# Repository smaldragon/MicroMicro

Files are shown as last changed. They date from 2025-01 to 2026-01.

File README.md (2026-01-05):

# MicroMicro

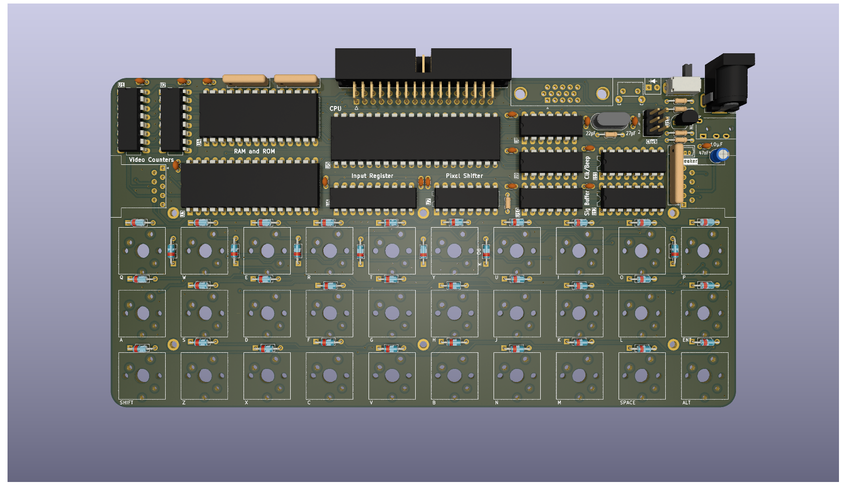
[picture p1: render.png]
PCB Render

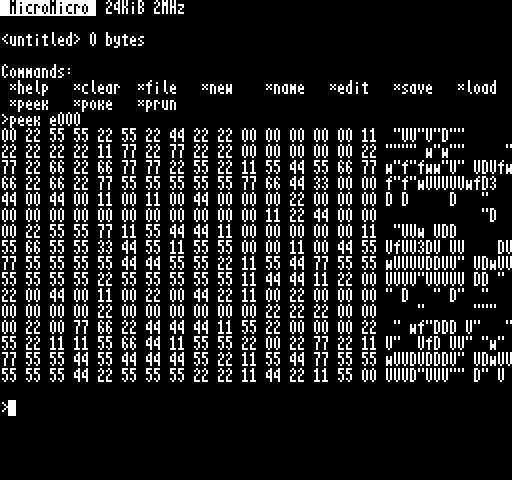
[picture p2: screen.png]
Emulator Screenshot


The MicroMicro (working name) is a project designed for a series I inteded(intend) to write, about how microcomputers work and how to go about developing one. It was designed to use a relatively small amount of integrated circuits (13), not use any programmable chips, microcontrollers or obselete parts, and to be a self-contained architecture that handles its own input and output (ie. not serial based).

With these requirements in mind, the overall specs are humble but capable:
* an 65c02 8bit cpu, running at 2Mhz
* 32KiB of ram, 8K of which are video ram
* 256x240 black and white display, via vga
* 1bit "beeper" audio
* Ultra-compact 30 Key keyboard using the "gherkin" layout
* Tape Interface for loading and storing data
* Cartridge port for rom programs and peripheral expansion
* 2 atari-style joystick ports

*Potential Features*
* custom case made from pcbs

The software side is still up in the air, but I'm aiming for the following features:
* A text editor
* An high-level programming language (undecided on which)
* A built-in assembler
* Saving and loading via the tape interface

This code would likely be custom and documented to follow the article structure of the hardware side of things.

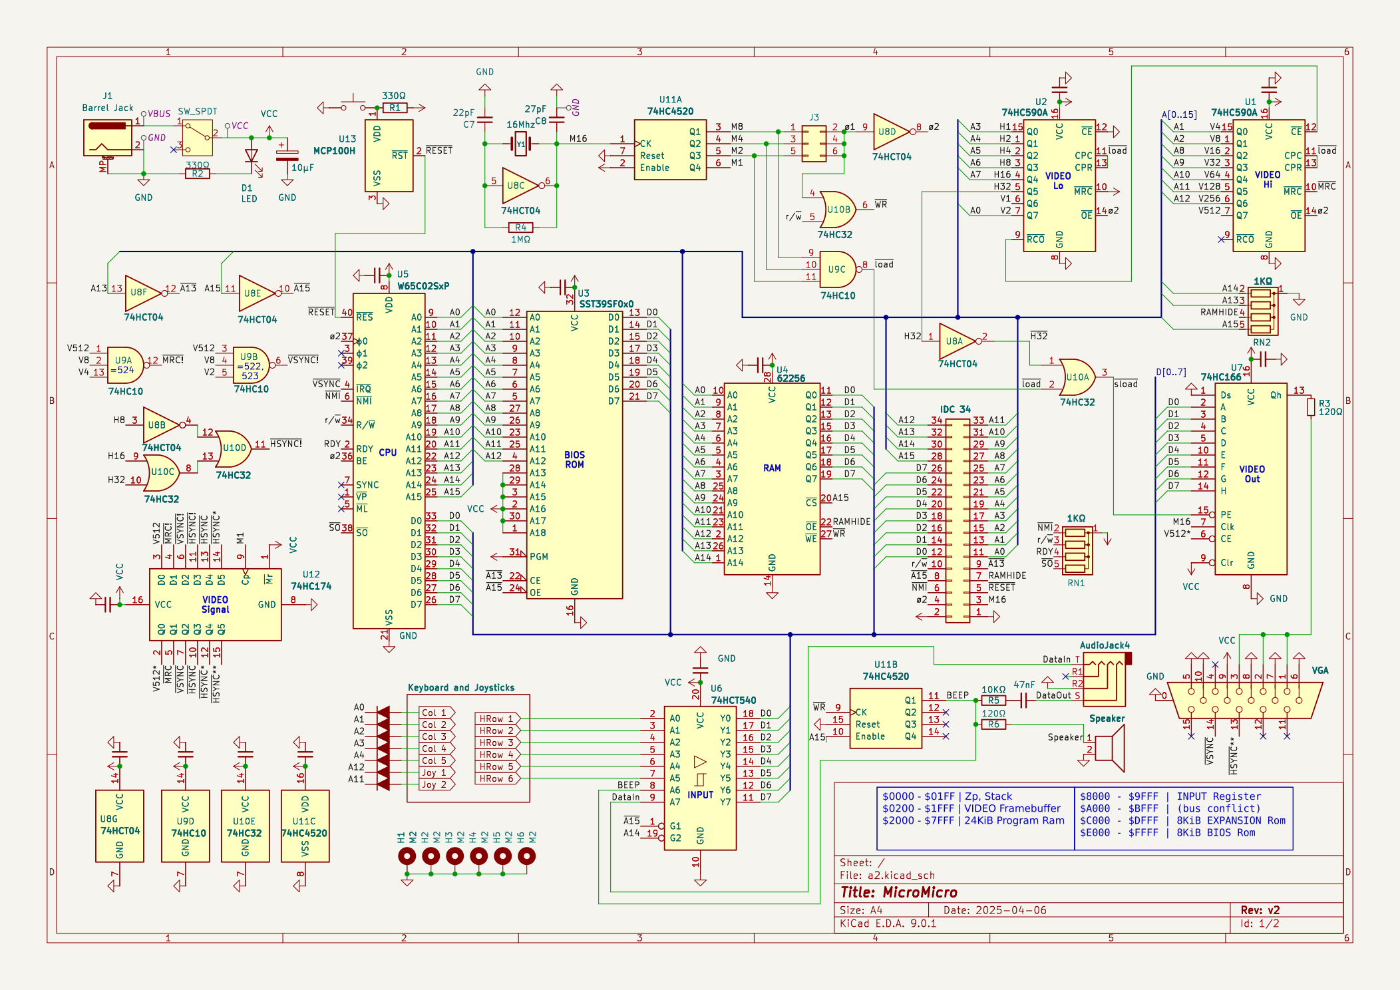
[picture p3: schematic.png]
System Schematic

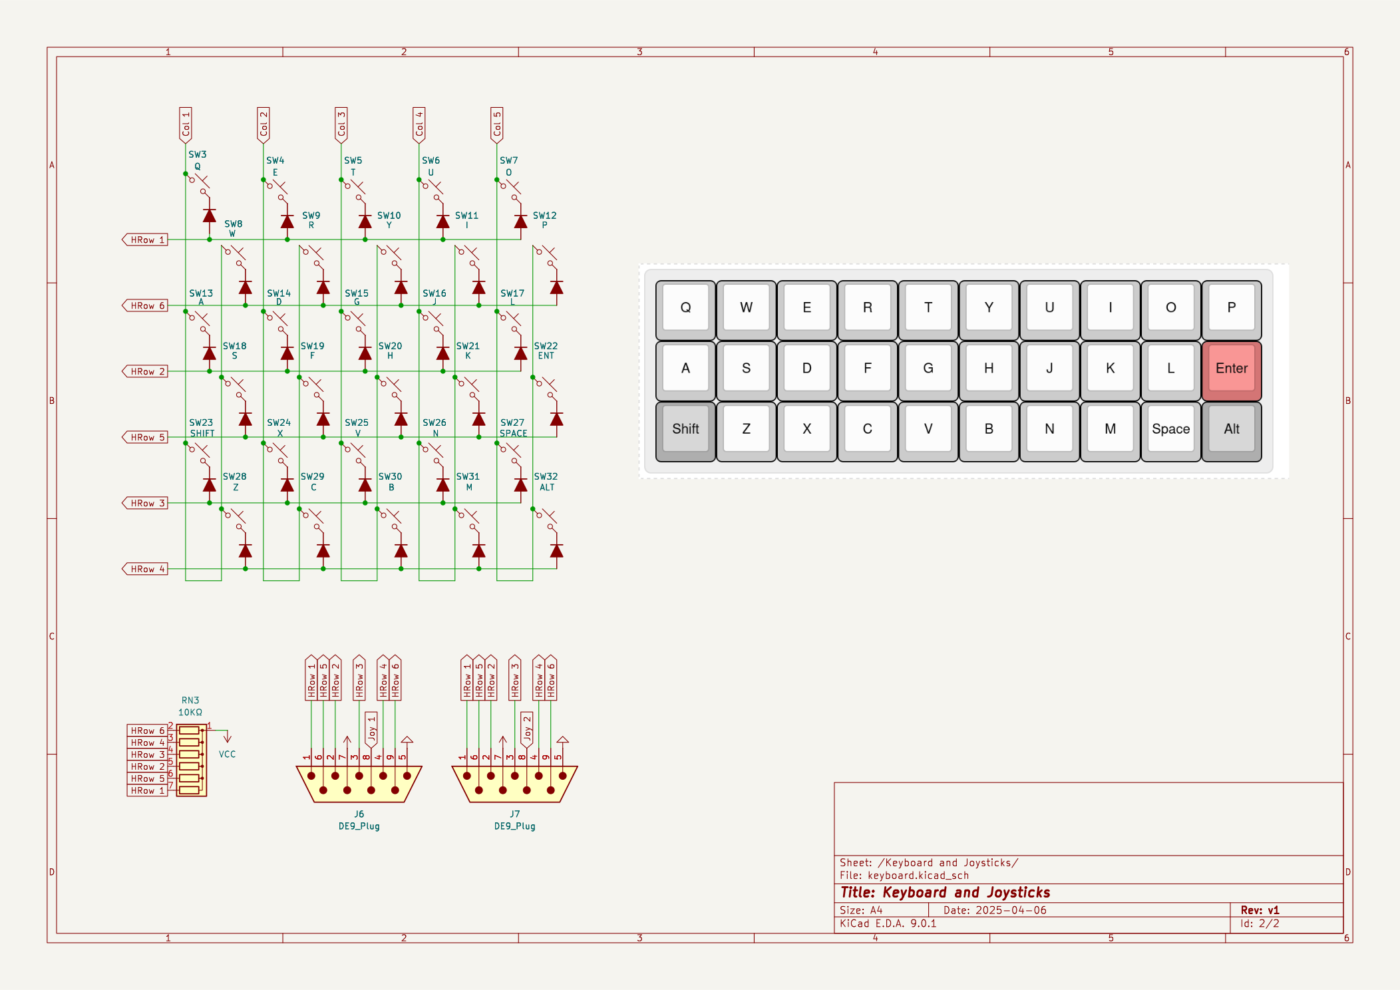
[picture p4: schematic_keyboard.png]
Keyboard Schematic


# Memory Map

```
+---------------------+-------+-----------+
| Name                | Size  | Location  |
+---------------------+-------+-----------+
| Zero Page & Stack   | 512   | 0000-01FF |
| Video Data          | 7680  | 0200-1FFF |
| General Purpose RAM | 24576 | 2000-7FFF |
| IO Registers        | 8192  | 8000-9FFF |
| Expansion ROM       | 8192  | C000-DFFF |
| Bios ROM            | 8192  | E000-FFFF |
+---------------------+-------+-----------+ 
* the area from A000-BFFF is an invalid bus conflict region
```

## Video Data Format

Each byte corresonds to a line of 8 horizontal pixels on the screen. The screen addresses are organized as 32x30 character cells of 8x8 pixels each. 8 Consecutive bytes build one character.

This non-linear format was chosen to speed up the rendering of characters to the screen.

## Keyboard and Joystick

The state of the keyboard and joysticks can be read at the following addresses:

```
+---------------------+----------+-------------------------+
| Name                | Address  | Value (bits 0-5)        |
+---------------------+----------+-------------------------+
| Keyboard Col 1      |   9FFE   |  Q   A  Shf  z   S   W  |
| Keyboard Col 2      |   9FFD   |  E   D   X   C   F   R  |
| Keyboard Col 3      |   9FFB   |  T   G   V   B   H   Y  |
| Keyboard Col 4      |   9FF7   |  U   J   N   M   K   I  |
| Keyboard Col 5      |   9FEF   |  O   L  SPC ALT ENT  P  |
| Joystick 1          |   8FFF   |  ↑   ↓   ←   →   L   R  |
| Joystick 2          |   97FF   |  ↑   ↓   ←   →   L   R  |
+---------------------+----------+-------------------------+
```

## Beeper and Tape Interface

The Beeper is a 1bit register that is used for both audio generation and to load and save programs to tape. It can be accessed through the following registers:

```
+---------------------+-------------+-----------+
| Name                | Address     | Value     |
+---------------------+-------------+-----------+
| State               | 9FFF (read) | TB.. .... |
| Toggle Beeper       | FFFF (write)| 0000 0000 |
+---------------------+-------------+-----------+
T = Tape Input
B = Beeper State (top 2 bits of input register)
```

The tape interface is a 4-pin trs connector that be connected directly to a computer using an appropriate aux cable.

> Note: While these registers can be accessed from alternative locations, the addresses and values on this table ensure no bus conflicts occur.

## Expansion Interface

The MicroMicro has an expansion interface that allows extending the base capabilities of the system in various ways:

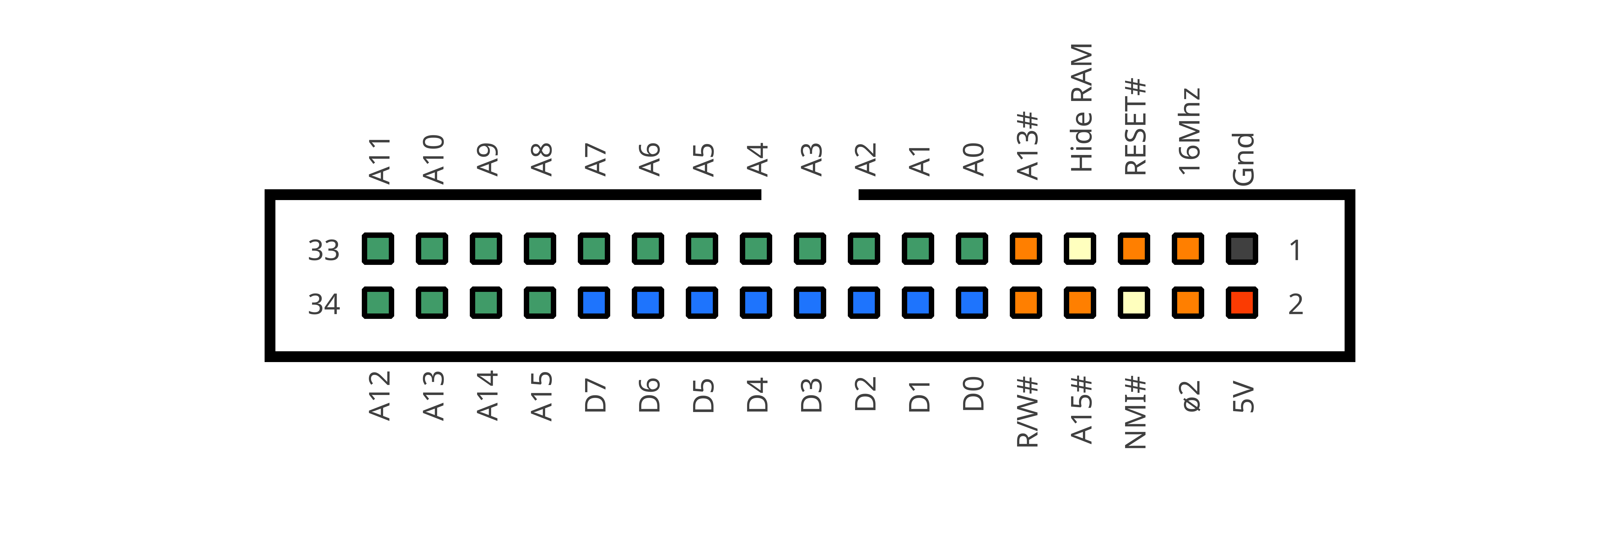
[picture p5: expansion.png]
Expansion Interface


## Generic Banked Expansion Rom

An 8KiB region is set aside in the memory map for expansion roms (`$C000-$DFFF`), the emulator implements a simple banked rom cartridge where the current bank can be switched by reading from `$A0xx`, where `xx` is the bank number, the selected bank is also automatically set to zero on reset.

The bios will automatically jump to address `$C008` on boot if it detects an expansion rom that begins with the sring `CART-RUN`.

Currently expansion roms can be loaded by dragging and dropping a file into the emulator window.

## IC List

The design uses only 12 integrated circuits:

* `65c02` - 8bit CPU
* `62256` - 32KiB SRAM
* `39SF010 or 28C64 or 27C256` - 8KiB Program ROM
* `74hc10` - Tripple 3inNAND
* `74hc14` - Hex inverter
* `74hc32` - Quad 2inOR
* `74hc166` - 8bit parallel-to-serial shift register
* `74hc174` - 6bit d-type latch
* `74hc541` - 8bit buffer
* `74hc590`*2 - 8bit Counters
* `74hc4520`- Dual 4bit Counters

# Operating System

The 8k bios provides a simple command line operating system with the following commands:

| Command | Description |
| --- | --- |
| `help` | Lists all available commands |
| `clear` | Clears the display |
| `file` | The Size and Name of the currently loaded file |
| `new` | Create a new file |
| `name <name>` | Rename the current file |
| `edit` | Open the file editor |
| `save` | Save file to tape |
| `load` | Load file from tape |
| `run` 	 | Run Loaded File |
| `peek <addr> <bytes>` | Read contents of Memory |
| `poke <addr> <bytes>` | Write to Memory |
| `prun <addr>` | Run a Machine Code Subroutine |

More info on the bios can be found [here](Docs/bios.md)

# Changelog

## A2

[Interactive BOM](https://raw.githack.com/smaldragon/MicroMicro/refs/heads/main/Kicad/a2/bom/ibom.html)

* Reset is now performed using a MCP-100 voltage supervisor, this primarly serves to replace the 74HC14 Schmitt Trigger Hex NOT with a 74HCT04, reducing delays, improving reliabiliy of the clock oscillator circuit, and freeing 1 NOT gate for the video circuit
* Video glitches (leftmost pixel column doubled on right, junk at the bottom of the screen) are now gone
* VGA video output is now better centered on the screen
* The small 6mm buzzer has been replaced with an header for a small speaker, improving volume and sound clarity
* Filtering capacitor added to data output
* Needless diodes removed
* Fixed footprint for headphone jack
* 2 additional M2 screw posts added to the center region of the board
* Schematic rearranged

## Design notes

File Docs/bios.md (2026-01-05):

# BIOS Programming Interface

## Interrupt Vectors

The Interrupt Vectors point to the following addresses in Zero Page:

* `$10-$12` - **IRQ** Video Interrupt
* `$13-$15` - **NMI** Expansion Port Interrupt

## Font

The font is located at the start of the BIOS ROM and includes 96 ASCII characters in a 4x8 resolution (768 bytes total):
* `$E000-$E05F` - Row 1
* `$E060-$E1BF` - Row 2
* `$E0C0-$E11F` - Row 3
* `$E120-$E17F` - Row 4
* `$E180-$E1DF` - Row 5
* `$E1E0-$E23F` - Row 6
* `$E240-$E2BF` - Row 7
* `$E2A0-$E2FF` - Row 8

## Control Codes

The MicroMicro uses the following control codes:

## Function API

There is a function jump table located in page $FF00. The current functions are:

* `jsr $FF00` **CIN**  - Returns input character into A (0 if none)
* `jsr $FF03` **COUT**  - Print character in A
* `jsr $FF06` **BEEP** - Pitched sound based on A
* `jsr $FF09` **CMDIN** - Read Command-Line Input, returns start of string into X (zero page address), length of string into Y
* `jsr $FF0C` **GETCURSOR** - Get Current Cursor Position in X (0-63) and Y (0-29)
* `jsr $FF0F` **SETCURSOR** - Set Current Cursor Position using X (0-63) and Y (0-29)

### Control Codes

`CIN`/`COUT` use the following control codes:

* `$03` **ETX** - Escape/Ctrl-C
* `$07` **BEL** - Play a Beep
* `$08` **BS**  - Backspace
* `$0A` **LF**  - Newline
* `$0C` **FF**  - Clear the screen
* `$0D` **CR**  - Return to start of line
* `$10` **CHI** - Turn on Highlighted Text
* `$11` **CNO** - Turn off Highlighted Text
* `$12` **FON** - Turn on the footer
* `$13` **FOF** - Turn off the footer
* `$7F` **DEL** - Erase character at cursor

## Run Carts

An extended rom subroutine will be automatically jumped to (`$C008`) on boot if the rom begins with 'CART-RUN'.

## Command Carts

An extended rom can add new commands to the bios if it beings with 'CART-CMD'. This extra command table beings at `$C008` and uses the same format as the main bios table.

Each table entry is 8 bytes, 6 bytes for the command name, followed by 2 bytes with the subroutine address, the table is terminated with a single zero-byte.

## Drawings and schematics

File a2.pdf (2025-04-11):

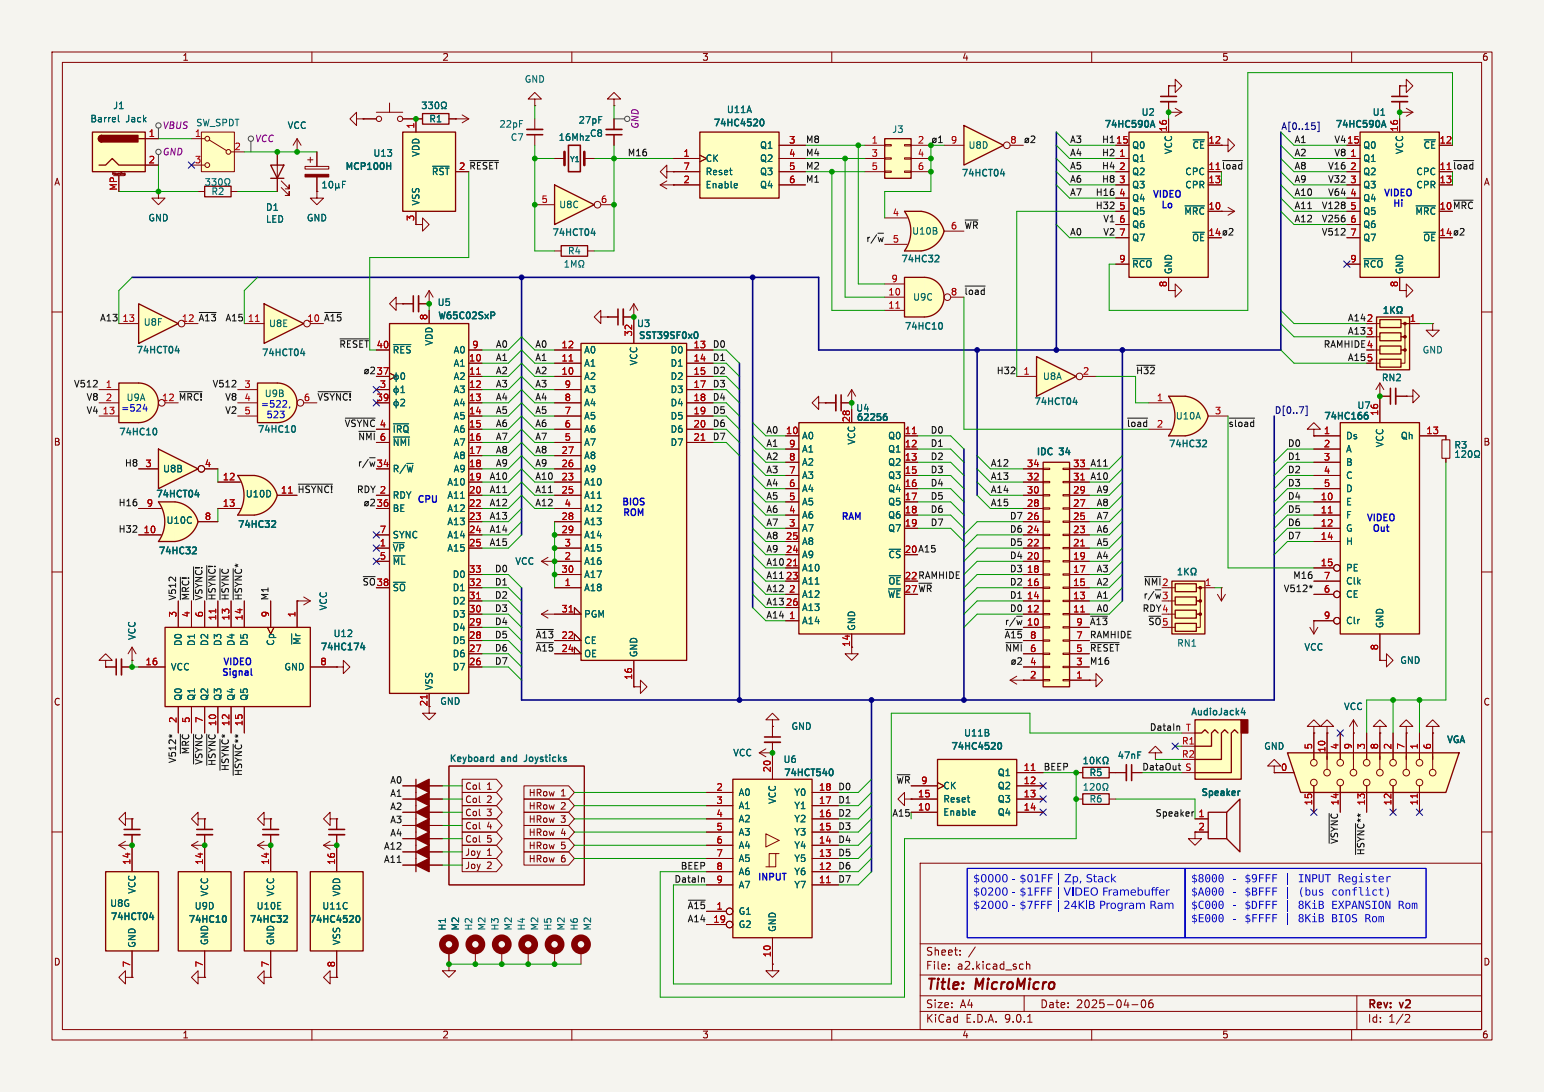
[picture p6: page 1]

8 Q0 15 Q1 1 Q2 2 Q3 3 Q4 4 Q5 5 Q6 6 Q7 7 ~{RCO} 9 U1
~{CE} 12 CPC 11 CPR 13 ~{MRC} 10 ~{OE} 14 VCC 16 GND

7 U3SST39SF0x0 VCC 32 GND 16 A0 12 A1 11 A2 10 A3 9 A4 8 A5 7 A6 6 A7 5 A8 27 A9 26 A10 23 A11 25 A12 4 A13 28 A14 29 A15 3 A16 2 A17 30 A18 1 PGM 31 CE 22 OE 24 D0 13 D1 14 D2 15 D3 17 D4 18 D5 19 D6 20 D7 21 VCC H1 M2

File: a2.kicad_sch Sheet: / Keyboard and Joysticks VCC 14 GND

Joy 1 Col 5 Col 1 Col 3 Col 2

$0000 - $01FF | Zp, Stack
$0200 - $1FFF | VIDEO Framebuffer $2000 - $7FFF | 24KiB Program Ram

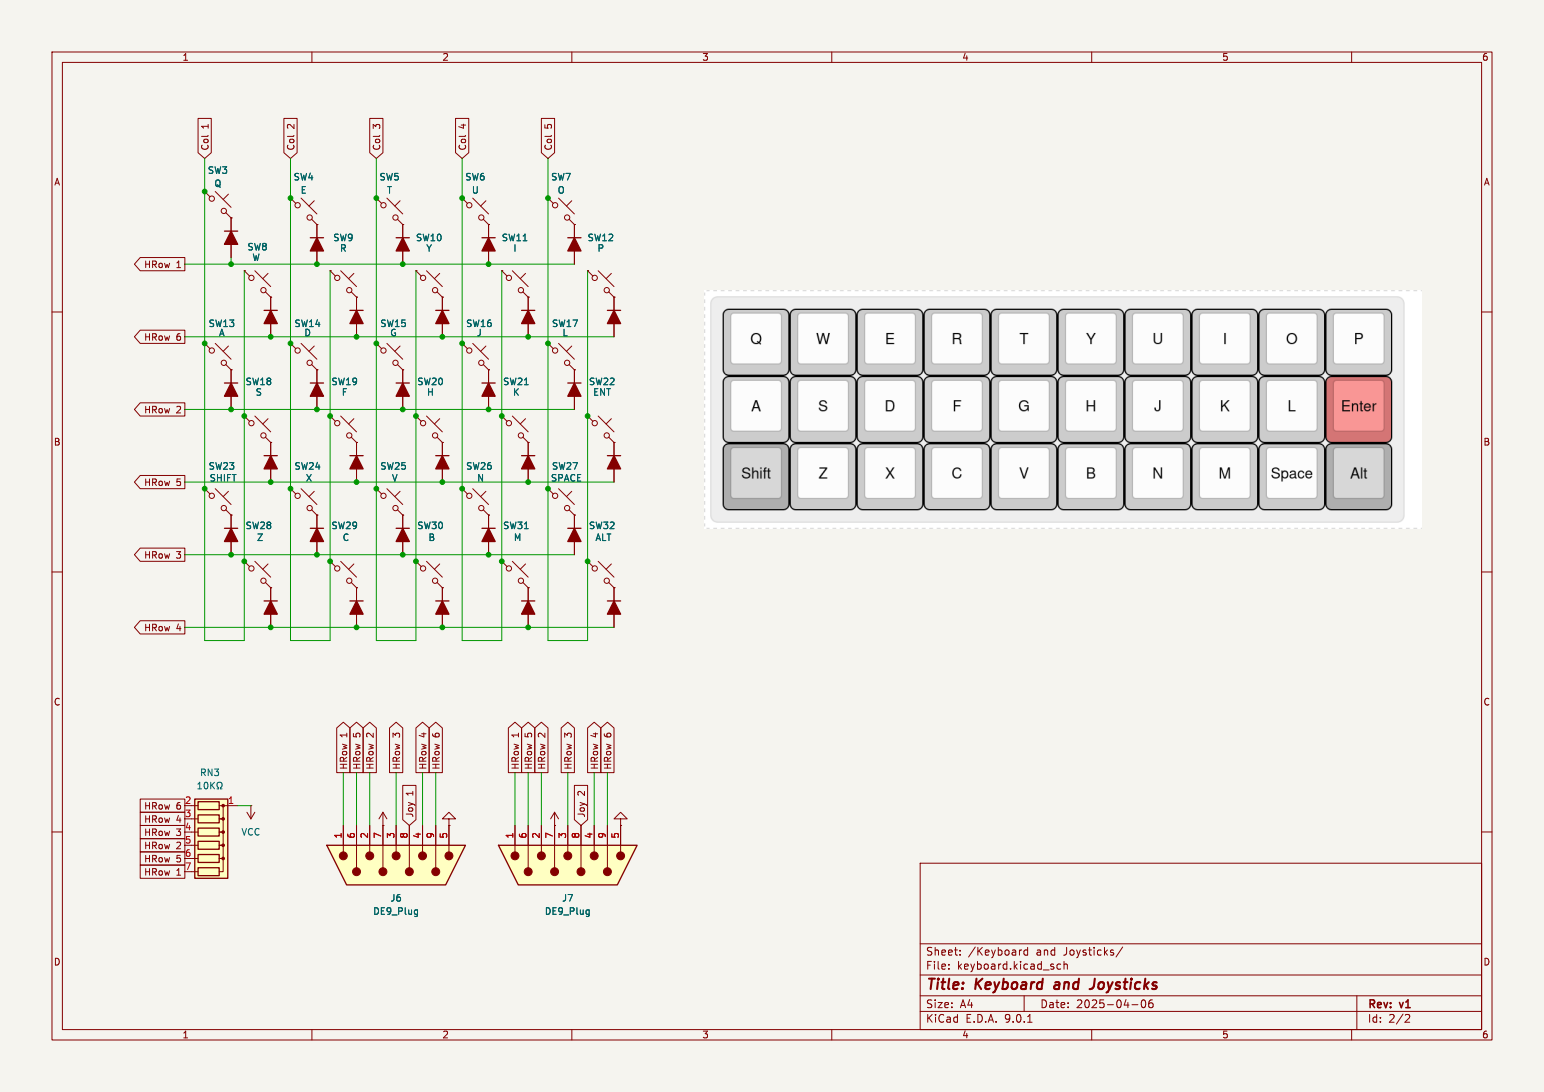
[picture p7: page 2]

Id: 2/2 Title: Keyboard and Joysticks

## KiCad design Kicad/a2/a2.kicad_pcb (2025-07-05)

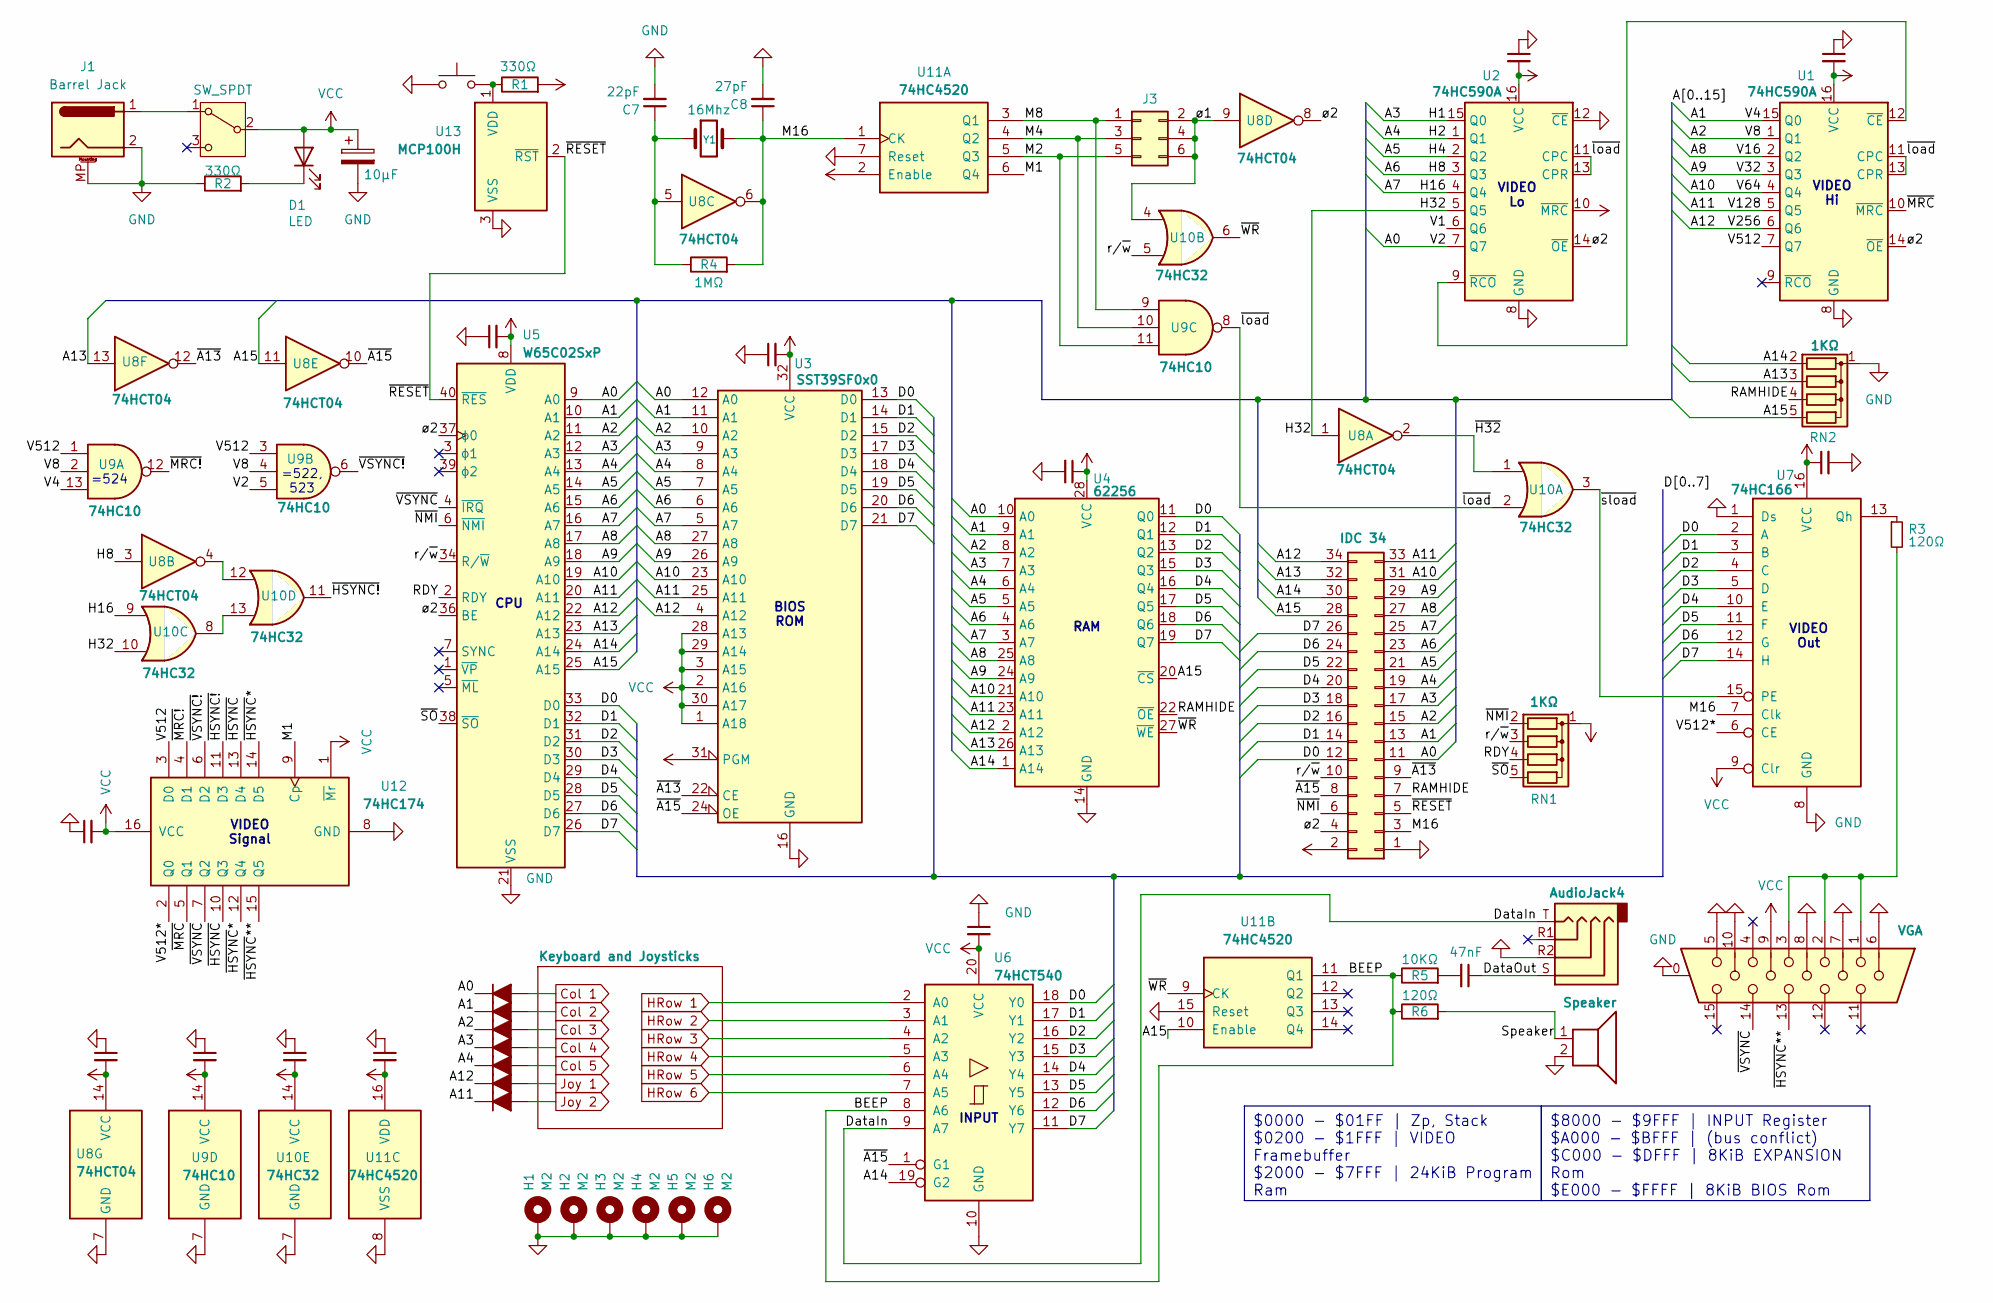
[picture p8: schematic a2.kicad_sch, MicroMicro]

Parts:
C1, C2, C3, C4, C5, C9, C11, C12, C14, C15, C16, C17: 100nF; C_Disc_D3.0mm_W1.6mm_P2.50mm
C6: 10µF; CP_Radial_D4.0mm_P1.50mm
C7: 22pF; C_Disc_D3.0mm_W1.6mm_P2.50mm
C8: 27pF; C_Disc_D3.0mm_W1.6mm_P2.50mm
C10: 47nF; C_Disc_D3.0mm_W1.6mm_P2.50mm
D1: LED; LED_Indicator_D3.0mm_W4.6mm_L6.5mm
D2, D3, D4, D5, D6, D12, D13: 1N4148; D_DO-35_SOD27_P7.62mm_Horizontal
H1, H2, H3, H4, H5, H6: M2; MountingHole_2.2mm_M2_ISO7380_Pad
J1: Barrel Jack; BarrelJack_GCT_DCJ200-10-A_Horizontal
J2: IDC 34; IDC-Header_2x17_P2.54mm_Horizontal
J3: Conn_02x03_Odd_Even; PinHeader_2x03_P2.54mm_Vertical
J4: VGA; DSUB-15-HD_Female_Horizontal_P2.29x1.98mm_EdgePinOffset3.03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
J5: AudioJack4; Jack_3.5mm_PJ320A_Horizontal
LS1: Speaker; Molex_PicoBlade_53047-0210_1x02_P1.25mm_Vertical
R1, R2: 330Ω; R_Axial_DIN0204_L3.6mm_D1.6mm_P7.62mm_Horizontal
R3: 120Ω; R_Axial_DIN0204_L3.6mm_D1.6mm_P5.08mm_Horizontal
R4: 1MΩ; R_Axial_DIN0204_L3.6mm_D1.6mm_P7.62mm_Horizontal
R5: 10KΩ; R_Axial_DIN0204_L3.6mm_D1.6mm_P7.62mm_Horizontal
R6: 120Ω; R_Axial_DIN0204_L3.6mm_D1.6mm_P7.62mm_Horizontal
RN1, RN2: 1KΩ; R_Array_SIP5
SW1: SW_Push; SW_Tactile_SKHH_Angled
SW2: SW_SPDT; SW_Slide_SPDT_Angled_CK_OS102011MA1Q
U1, U2: 74HC590A; DIP-16_W7.62mm_LongPads
U3: SST39SF0x0; DIP-32_W15.24mm_LongPads
U4: 62256; DIP-28_W15.24mm_LongPads
U5: W65C02SxP; DIP-40_W15.24mm
U6: 74HCT540; DIP-20_W7.62mm_LongPads
U7: 74HC166; DIP-16_W7.62mm_LongPads
U8: 74HCT04; DIP-14_W7.62mm_LongPads
U9: 74HC10; DIP-14_W7.62mm_LongPads
U10: 74HC32; DIP-14_W7.62mm_LongPads
U11: 74HC4520; DIP-16_W7.62mm_LongPads
U12: 74HC174; DIP-16_W7.62mm_LongPads
U13: MCP100H; TO-92
Y1: 16Mhz; Crystal_HC49-4H_Vertical

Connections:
/A0: D2.1 (K), J2.11, U2.7 (Q7), U3.12 (A0), U4.10 (A0), U5.9 (A0), U9.5
/A1: D3.1 (K), J2.13, U1.15 (Q0), U3.11 (A1), U4.9 (A1), U5.10 (A1), U9.13
/A2: D4.1 (K), J2.15, U1.1 (Q1), U3.10 (A2), U4.8 (A2), U5.11 (A2), U9.2, U9.4
/A3: D5.1 (K), J2.17, U2.15 (Q0), U3.9 (A3), U4.7 (A3), U5.12 (A3)
/A4: D6.1 (K), J2.19, U2.1 (Q1), U3.8 (A4), U4.6 (A4), U5.13 (A4)
/A5: J2.21, U2.2 (Q2), U3.7 (A5), U4.5 (A5), U5.14 (A5)
/A6: J2.23, U2.3 (Q3), U3.6 (A6), U4.4 (A6), U5.15 (A6), U8.3
/A7: J2.25, U2.4 (Q4), U3.5 (A7), U4.3 (A7), U5.16 (A7), U10.9
/A8: J2.27, U1.2 (Q2), U3.27 (A8), U4.25 (A8), U5.17 (A8)
/A9: J2.29, U1.3 (Q3), U3.26 (A9), U4.24 (A9), U5.18 (A9)
/A10: J2.31, U1.4 (Q4), U3.23 (A10), U4.21 (A10), U5.19 (A10)
/A11: D13.1 (K), J2.33, U1.5 (Q5), U3.25 (A11), U4.23 (A11), U5.20 (A11)
/A12: D12.1 (K), J2.34, U1.6 (Q6), U3.4 (A12), U4.2 (A12), U5.22 (A12)
/A13: J2.32, RN2.3 (R2), U4.26 (A13), U5.23 (A13), U8.13
/A14: J2.30, RN2.2 (R1), U4.1 (A14), U5.24 (A14), U6.19 (G2)
/A15: J2.28, RN2.5 (R4), U4.20 (~CS), U5.25 (A15), U8.11, U11.10 (Enable)
/BEEP: R5.1, R6.1, U6.8 (A6), U11.11 (Q1)
/D0: J2.12, U3.13 (D0), U4.11 (Q0), U5.33 (D0), U6.18 (Y0), U7.2 (A)
/D1: J2.14, U3.14 (D1), U4.12 (Q1), U5.32 (D1), U6.17 (Y1), U7.3 (B)
/D2: J2.16, U3.15 (D2), U4.13 (Q2), U5.31 (D2), U6.16 (Y2), U7.4 (C)
/D3: J2.18, U3.17 (D3), U4.15 (Q3), U5.30 (D3), U6.15 (Y3), U7.5 (D)
/D4: J2.20, U3.18 (D4), U4.16 (Q4), U5.29 (D4), U6.14 (Y4), U7.10 (E)
/D5: J2.22, U3.19 (D5), U4.17 (Q5), U5.28 (D5), U6.13 (Y5), U7.11 (F)
/D6: J2.24, U3.20 (D6), U4.18 (Q6), U5.27 (D6), U6.12 (Y6), U7.12 (G)
/D7: J2.26, U3.21 (D7), U4.19 (Q7), U5.26 (D7), U6.11 (Y7), U7.14 (H)
/DataIn: J5.T, U6.9 (A7)
/DataOut: C10.1, J5.S
/H32: U2.5 (Q5), U8.1, U10.10
/M1: U11.6 (Q4), U12.9 (Cp)
/M2: J3.5, U9.11, U11.5 (Q3)
/M4: J3.3, U9.10, U11.4 (Q2)
/M8: J3.1, U9.9, U11.3 (Q1)
/M16: C8.1, J2.3, R4.2, U7.7 (Clk), U8.6, U11.1 (CK), Y1.2
/RAMHIDE: J2.7, RN2.4 (R3), U4.22 (~OE)
/RDY: RN1.4 (R3), U5.2 (RDY)
/Speaker: LS1.1, R6.2
/V1: U2.6 (Q6)
/V512: U1.7 (Q7), U9.1, U9.3, U12.3 (D0)
/V512*: U7.6 (CE), U12.2 (Q0)
/r/~w: J2.10, RN1.3 (R2), U5.34 (R/~W), U10.5
/~A13: J2.9, U3.22 (CE), U8.12
/~A15: J2.8, U3.24 (OE), U6.1 (G1), U8.10
/~H32: U8.2, U10.1
/~HSYNC!: U10.11, U12.11 (D3)
/~HSYNC: U12.10 (Q3), U12.13 (D4)
/~HSYNC*: U12.12 (Q4), U12.14 (D5)
/~HSYNC**: J4.13, U12.15 (Q5)
/~MRC!: U9.12, U12.4 (D1)
/~MRC: U1.10 (~MRC), U12.5 (Q1)
/~NMI: J2.6, RN1.2 (R1), U5.6 (~NMI)
/~RESET: J2.5, U5.40 (~RES), U13.2 (~RST)
/~SO: RN1.5 (R4), U5.38 (~SO)
/~VSYNC!: U9.6, U12.6 (D2)
/~VSYNC: J4.14, U5.4 (~IRQ), U12.7 (Q2)
/~WR: U4.27 (~WE), U10.6, U11.9 (CK)
/~load: U1.11 (CPC), U1.13 (CPR), U2.11 (CPC), U2.13 (CPR), U9.8, U10.2
/~sload: U7.15 (PE), U10.3
/ø1: J3.2, J3.4, J3.6, U8.9, U10.4
/ø2: J2.4, U1.14 (~OE), U2.14 (~OE), U5.36 (BE), U5.37 (ϕ0), U8.8
Col 1: D2.2 (A); also elsewhere on the board
Col 2: D3.2 (A); also elsewhere on the board
Col 3: D4.2 (A); also elsewhere on the board
Col 4: D5.2 (A); also elsewhere on the board
Col 5: D6.2 (A); also elsewhere on the board
GND: C1.1, C2.1, C3.2, C4.2, C5.1, C6.2, C7.2, C8.2, C9.1, C11.1, C12.1, C14.1, C15.1, C16.1, C17.1, H1.1, H2.1, H3.1, H4.1, H5.1, H6.1, J1.2, J1.MP (MountPin), J2.1, J4.0, J4.5, J4.6, J4.7, J4.8, J4.10, J5.R2, LS1.2, R2.1, RN2.1 (common), SW1.1, U1.8 (GND), U2.8 (GND), U2.12 (~CE), U3.16 (GND), U4.14 (GND), U5.21 (VSS), U6.10 (GND), U7.1 (Ds), U7.8 (GND), U8.7 (GND), U9.7 (GND), U10.7 (GND), U11.7 (Reset), U11.8 (VSS), U11.15 (Reset), U12.8 (GND), U13.3 (VSS); also elsewhere on the board
HRow 1: U6.2 (A0); also elsewhere on the board
HRow 2: U6.3 (A1); also elsewhere on the board
HRow 3: U6.4 (A2); also elsewhere on the board
HRow 4: U6.5 (A3); also elsewhere on the board
HRow 5: U6.6 (A4); also elsewhere on the board
HRow 6: U6.7 (A5); also elsewhere on the board
Joy 1: D12.2 (A); also elsewhere on the board
Joy 2: D13.2 (A); also elsewhere on the board
unnamed: C7.1, R4.1, U8.5, Y1.1
unnamed: C10.2, R5.2
unnamed: D1.1 (K), R2.2
unnamed: J4.1, J4.2, J4.3, R3.2
unnamed: J1.1, SW2.1 (A)
unnamed: U1.12 (~CE), U2.9 (~RCO)
unnamed: R3.1, U7.13 (Qh)
unnamed: U8.4, U10.12
unnamed: U10.8, U10.13
unnamed: R1.1, SW1.2, U13.1 (VDD)
VCC: C1.2, C2.2, C3.1, C4.1, C5.2, C6.1, C9.2, C11.2, C12.2, C14.2, C15.2, C16.2, C17.2, D1.2 (A), J2.2, J4.9, R1.2, RN1.1 (common), SW2.2 (B), U1.16 (VCC), U2.10 (~MRC), U2.16 (VCC), U3.1 (A18), U3.2 (A16), U3.3 (A15), U3.28 (A13), U3.29 (A14), U3.30 (A17), U3.31 (PGM), U3.32 (VCC), U4.28 (VCC), U5.8 (VDD), U6.20 (VCC), U7.9 (Clr), U7.16 (VCC), U8.14 (VCC), U9.14 (VCC), U10.14 (VCC), U11.2 (Enable), U11.16 (VDD), U12.1 (~Mr), U12.16 (VCC); also elsewhere on the board

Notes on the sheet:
VIDEO Lo
=524
BIOS ROM
VIDEO Signal
=522, 523
INPUT
RAM
VIDEO Out
VIDEO Hi
CPU
$8000 - $9FFF | INPUT Register $A000 - $BFFF | (bus conflict) $C000 - $DFFF | 8KiB EXPANSION Rom $E000 - $FFFF | 8KiB BIOS Rom
$0000 - $01FF | Zp, Stack $0200 - $1FFF | VIDEO Framebuffer $2000 - $7FFF | 24KiB Program Ram

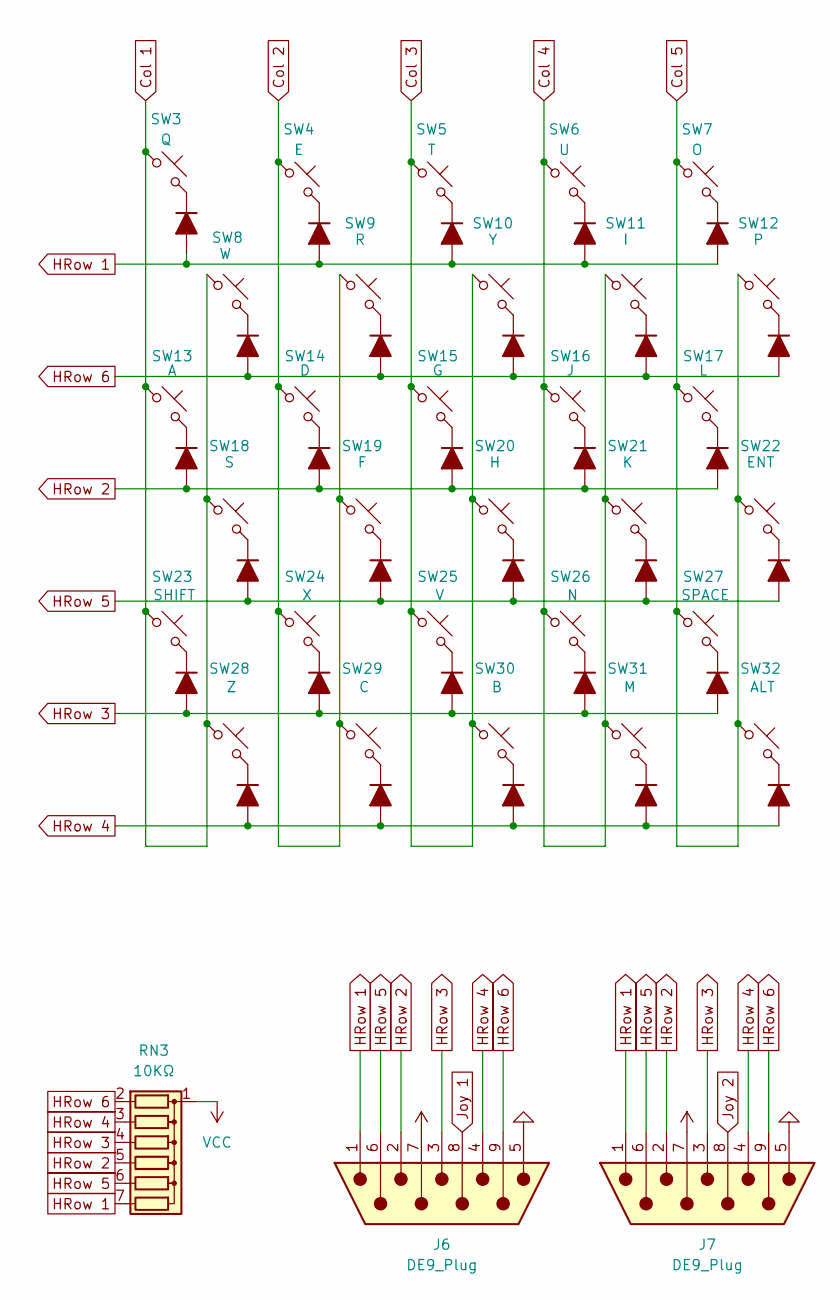
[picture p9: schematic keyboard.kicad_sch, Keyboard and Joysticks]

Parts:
D7, D8, D9, D10, D11, D14, D15, D16, D17, D18, D19, D20, D21, D22, D23, D24, D25, D26, D27, D28, D29, D30, D31, D32, D33, D34, D35, D36, D37, D38: 1N4148; D_DO-35_SOD27_P7.62mm_Horizontal
J6, J7: DE9_Plug; DSUB9-Atari
RN3: 10KΩ; R_Array_SIP7
SW3: Q; SW_Redragon_MX_LowProfile_PCB_1.00u_Other
SW4: E; SW_Redragon_MX_LowProfile_PCB_1.00u_Other
SW5: T; SW_Redragon_MX_LowProfile_PCB_1.00u_Other
SW6: U; SW_Redragon_MX_LowProfile_PCB_1.00u_Other
SW7: O; SW_Redragon_MX_LowProfile_PCB_1.00u_Other
SW8: W; SW_Redragon_MX_LowProfile_PCB_1.00u_Other
SW9: R; SW_Redragon_MX_LowProfile_PCB_1.00u_Other
SW10: Y; SW_Redragon_MX_LowProfile_PCB_1.00u_Other
SW11: I; SW_Redragon_MX_LowProfile_PCB_1.00u_Other
SW12: P; SW_Redragon_MX_LowProfile_PCB_1.00u_Other
SW13: A; SW_Redragon_MX_LowProfile_PCB_1.00u_Other
SW14: D; SW_Redragon_MX_LowProfile_PCB_1.00u_Other
SW15: G; SW_Redragon_MX_LowProfile_PCB_1.00u_Other
SW16: J; SW_Redragon_MX_LowProfile_PCB_1.00u_Other
SW17: L; SW_Redragon_MX_LowProfile_PCB_1.00u_Other
SW18: S; SW_Redragon_MX_LowProfile_PCB_1.00u_Other
SW19: F; SW_Redragon_MX_LowProfile_PCB_1.00u_Other
SW20: H; SW_Redragon_MX_LowProfile_PCB_1.00u_Other
SW21: K; SW_Redragon_MX_LowProfile_PCB_1.00u_Other
SW22: ENT; SW_Redragon_MX_LowProfile_PCB_1.00u_Other
SW23: SHIFT; SW_Redragon_MX_LowProfile_PCB_1.00u_Other
SW24: X; SW_Redragon_MX_LowProfile_PCB_1.00u_Other
SW25: V; SW_Redragon_MX_LowProfile_PCB_1.00u_Other
SW26: N; SW_Redragon_MX_LowProfile_PCB_1.00u_Other
SW27: SPACE; SW_Redragon_MX_LowProfile_PCB_1.00u_Other
SW28: Z; SW_Redragon_MX_LowProfile_PCB_1.00u_Other
SW29: C; SW_Redragon_MX_LowProfile_PCB_1.00u_Other
SW30: B; SW_Redragon_MX_LowProfile_PCB_1.00u_Other
SW31: M; SW_Redragon_MX_LowProfile_PCB_1.00u_Other
SW32: ALT; SW_Redragon_MX_LowProfile_PCB_1.00u_Other

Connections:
Col 1: SW3.1, SW8.1, SW13.1, SW18.1, SW23.1, SW28.1; also elsewhere on the board
Col 2: SW4.1, SW9.1, SW14.1, SW19.1, SW24.1, SW29.1; also elsewhere on the board
Col 3: SW5.1, SW10.1, SW15.1, SW20.1, SW25.1, SW30.1; also elsewhere on the board
Col 4: SW6.1, SW11.1, SW16.1, SW21.1, SW26.1, SW31.1; also elsewhere on the board
Col 5: SW7.1, SW12.1, SW17.1, SW22.1, SW27.1, SW32.1; also elsewhere on the board
GND: J6.5, J7.5; also elsewhere on the board
HRow 1: D7.2 (A), D8.2 (A), D9.2 (A), D10.2 (A), D11.2 (A), J6.1, J7.1, RN3.7 (R6); also elsewhere on the board
HRow 2: D19.2 (A), D20.2 (A), D21.2 (A), D22.2 (A), D23.2 (A), J6.2, J7.2, RN3.5 (R4); also elsewhere on the board
HRow 3: D29.2 (A), D30.2 (A), D31.2 (A), D32.2 (A), D33.2 (A), J6.3, J7.3, RN3.4 (R3); also elsewhere on the board
HRow 4: D34.2 (A), D35.2 (A), D36.2 (A), D37.2 (A), D38.2 (A), J6.4, J7.4, RN3.3 (R2); also elsewhere on the board
HRow 5: D24.2 (A), D25.2 (A), D26.2 (A), D27.2 (A), D28.2 (A), J6.6, J7.6, RN3.6 (R5); also elsewhere on the board
HRow 6: D14.2 (A), D15.2 (A), D16.2 (A), D17.2 (A), D18.2 (A), J6.9, J7.9, RN3.2 (R1); also elsewhere on the board
Joy 1: J6.8; also elsewhere on the board
Joy 2: J7.8; also elsewhere on the board
unnamed: D7.1 (K), SW3.2
unnamed: D8.1 (K), SW4.2
unnamed: D9.1 (K), SW5.2
unnamed: D10.1 (K), SW6.2
unnamed: D11.1 (K), SW7.2
unnamed: D14.1 (K), SW8.2
unnamed: D15.1 (K), SW9.2
unnamed: D16.1 (K), SW10.2
unnamed: D17.1 (K), SW11.2
unnamed: D18.1 (K), SW12.2
unnamed: D19.1 (K), SW13.2
unnamed: D20.1 (K), SW14.2
unnamed: D21.1 (K), SW15.2
unnamed: D22.1 (K), SW16.2
unnamed: D23.1 (K), SW17.2
unnamed: D24.1 (K), SW18.2
unnamed: D25.1 (K), SW19.2
unnamed: D26.1 (K), SW20.2
unnamed: D27.1 (K), SW21.2
unnamed: D28.1 (K), SW22.2
unnamed: D29.1 (K), SW23.2
unnamed: D30.1 (K), SW24.2
unnamed: D31.1 (K), SW25.2
unnamed: D32.1 (K), SW26.2
unnamed: D33.1 (K), SW27.2
unnamed: D34.1 (K), SW28.2
unnamed: D35.1 (K), SW29.2
unnamed: D36.1 (K), SW30.2
unnamed: D37.1 (K), SW31.2
unnamed: D38.1 (K), SW32.2
VCC: J6.7, J7.7, RN3.1 (common); also elsewhere on the board

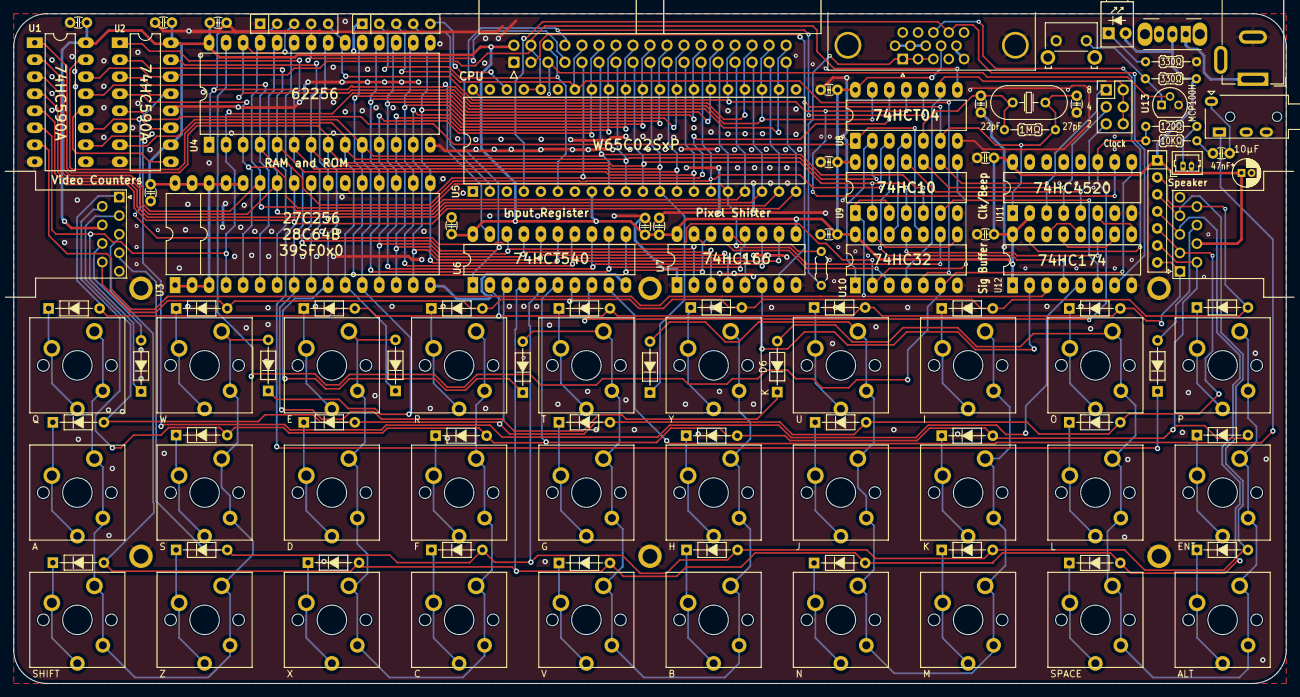
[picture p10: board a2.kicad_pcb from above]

Board: 2 copper layers, 190.0 x 100.0 mm, 123 parts (0 on the bottom side), 113 nets.

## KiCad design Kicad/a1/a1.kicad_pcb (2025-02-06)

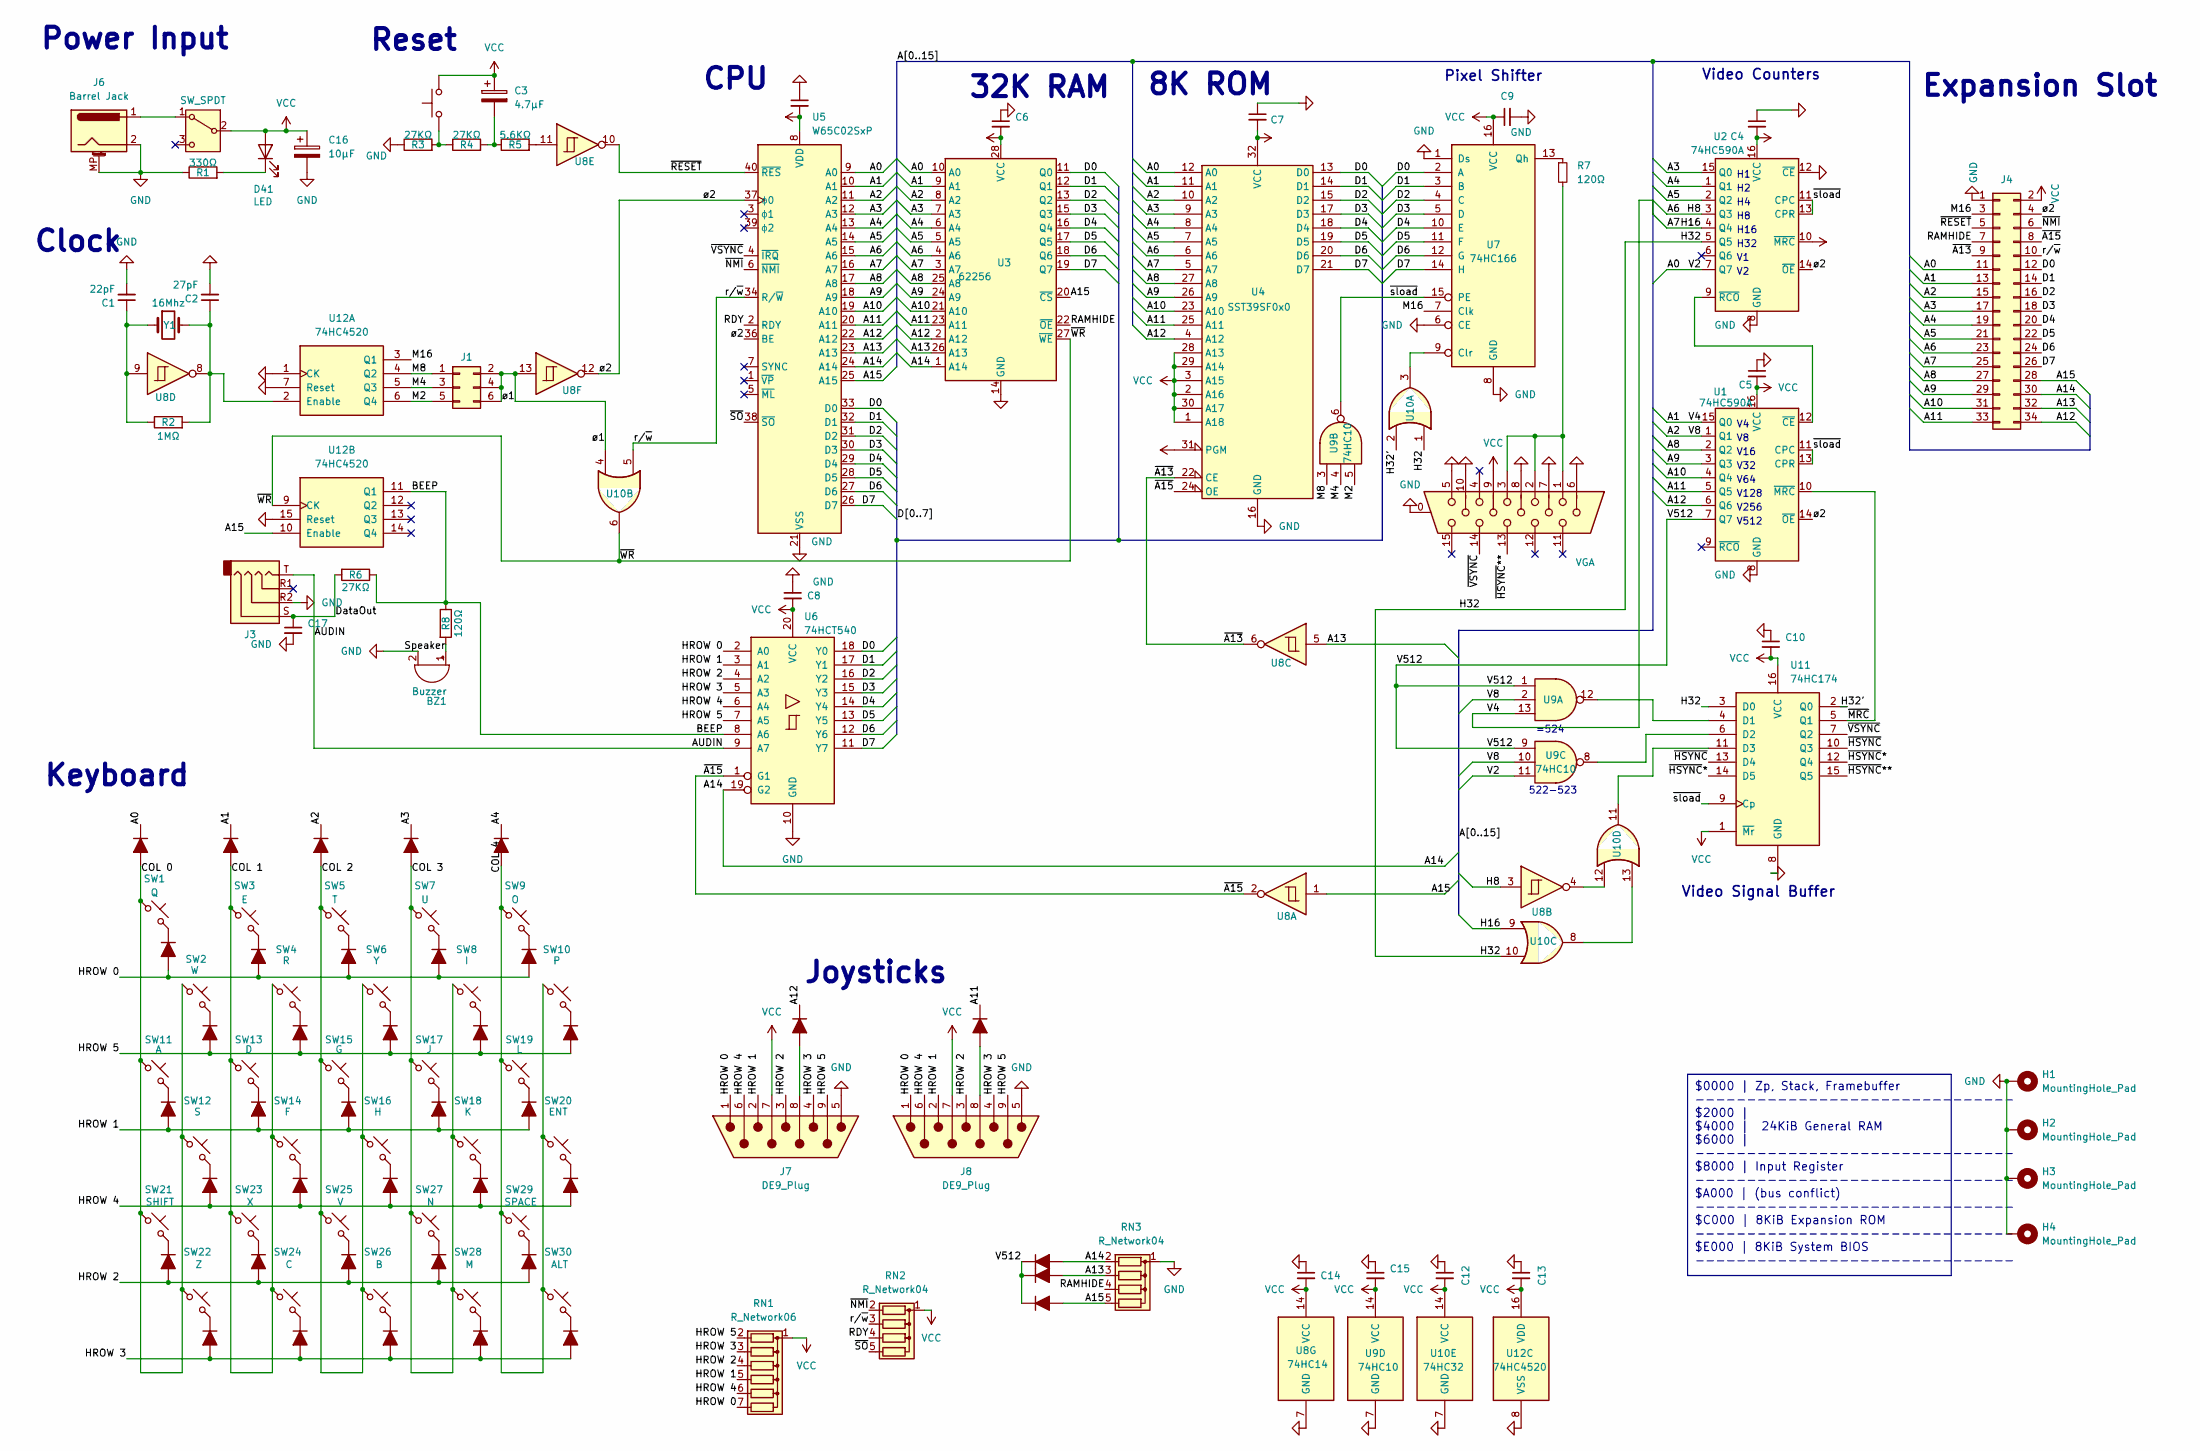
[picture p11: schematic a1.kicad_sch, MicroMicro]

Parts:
BZ1: Buzzer; MagneticBuzzer_Kingstate_KCG0601
C1: 22pF; C_Disc_D3.0mm_W1.6mm_P2.50mm
C2: 27pF; C_Disc_D3.0mm_W1.6mm_P2.50mm
C3: 4.7µF; CP_Radial_D4.0mm_P1.50mm
C4, C5, C6, C7, C8, C9, C10, C11, C12, C13, C14, C15, C17: 100nF; C_Disc_D3.0mm_W1.6mm_P2.50mm
C16: 10µF; CP_Radial_D5.0mm_P2.00mm
D1, D5, D6, D7, D8, D9, D10, D11, D12, D13, D14, D15, D16, D17, D18, D19, D20, D21, D22, D23, D24, D25, D26, D27, D28, D29, D30, D31, D32, D33, D34, D35, D36, D37, D38, D39, D40: 1N4148; D_DO-35_SOD27_P7.62mm_Horizontal
D2, D3, D4: 1N4148; D_DO-34_SOD68_P2.54mm_Vertical_KathodeUp
D41: LED; LED_Indicator_D3.0mm_W4.6mm_L6.5mm
H1, H2, H3, H4: MountingHole_Pad; MountingHole_2.2mm_M2_ISO7380_Pad
J1: Conn_02x03_Odd_Even; PinHeader_2x03_P2.54mm_Vertical
J2: VGA; DSUB-15-HD_Female_Horizontal_P2.29x1.98mm_EdgePinOffset3.03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
J3: AudioJack4; Jack_3.5mm_PJ320A_Horizontal
J4: Conn_02x17_Odd_Even; IDC-Header_2x17_P2.54mm_Horizontal
J6: Barrel Jack; BarrelJack_GCT_DCJ200-10-A_Horizontal
J7, J8: DE9_Plug; DSUB9-Atari
R1: 330Ω; R_Axial_DIN0204_L3.6mm_D1.6mm_P7.62mm_Horizontal
R2: 1MΩ; R_Axial_DIN0204_L3.6mm_D1.6mm_P7.62mm_Horizontal
R3, R4, R6: 27KΩ; R_Axial_DIN0204_L3.6mm_D1.6mm_P7.62mm_Horizontal
R5: 5.6KΩ; R_Axial_DIN0204_L3.6mm_D1.6mm_P7.62mm_Horizontal
R7, R8: 120Ω; R_Axial_DIN0204_L3.6mm_D1.6mm_P7.62mm_Horizontal
RN1: R_Network06; R_Array_SIP7
RN2, RN3: R_Network04; R_Array_SIP5
SW1: Q; SW_Redragon_MX_LowProfile_PCB_1.00u_Other
SW2: W; SW_Redragon_MX_LowProfile_PCB_1.00u_Other
SW3: E; SW_Redragon_MX_LowProfile_PCB_1.00u_Other
SW4: R; SW_Redragon_MX_LowProfile_PCB_1.00u_Other
SW5: T; SW_Redragon_MX_LowProfile_PCB_1.00u_Other
SW6: Y; SW_Redragon_MX_LowProfile_PCB_1.00u_Other
SW7: U; SW_Redragon_MX_LowProfile_PCB_1.00u_Other
SW8: I; SW_Redragon_MX_LowProfile_PCB_1.00u_Other
SW9: O; SW_Redragon_MX_LowProfile_PCB_1.00u_Other
SW10: P; SW_Redragon_MX_LowProfile_PCB_1.00u_Other
SW11: A; SW_Redragon_MX_LowProfile_PCB_1.00u_Other
SW12: S; SW_Redragon_MX_LowProfile_PCB_1.00u_Other
SW13: D; SW_Redragon_MX_LowProfile_PCB_1.00u_Other
SW14: F; SW_Redragon_MX_LowProfile_PCB_1.00u_Other
SW15: G; SW_Redragon_MX_LowProfile_PCB_1.00u_Other
SW16: H; SW_Redragon_MX_LowProfile_PCB_1.00u_Other
SW17: J; SW_Redragon_MX_LowProfile_PCB_1.00u_Other
SW18: K; SW_Redragon_MX_LowProfile_PCB_1.00u_Other
SW19: L; SW_Redragon_MX_LowProfile_PCB_1.00u_Other
SW20: ENT; SW_Redragon_MX_LowProfile_PCB_1.00u_Other
SW21: SHIFT; SW_Redragon_MX_LowProfile_PCB_1.00u_Other
SW22: Z; SW_Redragon_MX_LowProfile_PCB_1.00u_Other
SW23: X; SW_Redragon_MX_LowProfile_PCB_1.00u_Other
SW24: C; SW_Redragon_MX_LowProfile_PCB_1.00u_Other
SW25: V; SW_Redragon_MX_LowProfile_PCB_1.00u_Other
SW26: B; SW_Redragon_MX_LowProfile_PCB_1.00u_Other
SW27: N; SW_Redragon_MX_LowProfile_PCB_1.00u_Other
SW28: M; SW_Redragon_MX_LowProfile_PCB_1.00u_Other
SW29: SPACE; SW_Redragon_MX_LowProfile_PCB_1.00u_Other
SW30: ALT; SW_Redragon_MX_LowProfile_PCB_1.00u_Other
SW31: SW_Push; SW_Tactile_SKHH_Angled
SW32: SW_SPDT; SW_Slide_SPDT_Angled_CK_OS102011MA1Q
U1, U2: 74HC590A; DIP-16_W7.62mm_LongPads
U3: 62256; DIP-28_W15.24mm_LongPads
U4: SST39SF0x0; DIP-32_W15.24mm_LongPads
U5: W65C02SxP; DIP-40_W15.24mm
U6: 74HCT540; DIP-20_W7.62mm_LongPads
U7: 74HC166; DIP-16_W7.62mm_LongPads
U8: 74HC14; DIP-14_W7.62mm_LongPads
U9: 74HC10; DIP-14_W7.62mm_LongPads
U10: 74HC32; DIP-14_W7.62mm_LongPads
U11: 74HC174; DIP-16_W7.62mm_LongPads
U12: 74HC4520; DIP-16_W7.62mm_LongPads
Y1: 16Mhz; Crystal_HC49-4H_Vertical

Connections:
/A0: D1.1 (K), J4.11, U2.7 (Q7), U3.10 (A0), U4.12 (A0), U5.9 (A0), U9.11
/A1: D38.1 (K), J4.13, U1.15 (Q0), U3.9 (A1), U4.11 (A1), U5.10 (A1), U9.13
/A2: D39.1 (K), J4.15, U1.1 (Q1), U3.8 (A2), U4.10 (A2), U5.11 (A2), U9.2, U9.10
/A3: D40.1 (K), J4.17, U2.15 (Q0), U3.7 (A3), U4.9 (A3), U5.12 (A3)
/A4: D37.1 (K), J4.19, U2.1 (Q1), U3.6 (A4), U4.8 (A4), U5.13 (A4)
/A5: J4.21, U2.2 (Q2), U3.5 (A5), U4.7 (A5), U5.14 (A5)
/A6: J4.23, U2.3 (Q3), U3.4 (A6), U4.6 (A6), U5.15 (A6), U8.3
/A7: J4.25, U2.4 (Q4), U3.3 (A7), U4.5 (A7), U5.16 (A7), U10.9
/A8: J4.27, U1.2 (Q2), U3.25 (A8), U4.27 (A8), U5.17 (A8)
/A9: J4.29, U1.3 (Q3), U3.24 (A9), U4.26 (A9), U5.18 (A9)
/A10: J4.31, U1.4 (Q4), U3.21 (A10), U4.23 (A10), U5.19 (A10)
/A11: D5.1 (K), J4.33, U1.5 (Q5), U3.23 (A11), U4.25 (A11), U5.20 (A11)
/A12: D6.1 (K), J4.34, U1.6 (Q6), U3.2 (A12), U4.4 (A12), U5.22 (A12)
/A13: D3.2 (A), J4.32, RN3.3 (R2), U3.26 (A13), U5.23 (A13), U8.5
/A14: D2.2 (A), J4.30, RN3.2 (R1), U3.1 (A14), U5.24 (A14), U6.19 (G2)
/A15: D4.2 (A), J4.28, RN3.5 (R4), U3.20 (~CS), U5.25 (A15), U8.1, U12.10 (Enable)
/AUDIN: J3.T, U6.9 (A7)
/BEEP: R6.1, R8.1, U6.8 (A6), U12.11 (Q1)
/COL 0: D1.2 (A), SW1.1, SW2.1, SW11.1, SW12.1, SW21.1, SW22.1
/COL 1: D38.2 (A), SW3.1, SW4.1, SW13.1, SW14.1, SW23.1, SW24.1
/COL 2: D39.2 (A), SW5.1, SW6.1, SW15.1, SW16.1, SW25.1, SW26.1
/COL 3: D40.2 (A), SW7.1, SW8.1, SW17.1, SW18.1, SW27.1, SW28.1
/COL 4: D37.2 (A), SW9.1, SW10.1, SW19.1, SW20.1, SW29.1, SW30.1
/D0: J4.12, U3.11 (Q0), U4.13 (D0), U5.33 (D0), U6.18 (Y0), U7.2 (A)
/D1: J4.14, U3.12 (Q1), U4.14 (D1), U5.32 (D1), U6.17 (Y1), U7.3 (B)
/D2: J4.16, U3.13 (Q2), U4.15 (D2), U5.31 (D2), U6.16 (Y2), U7.4 (C)
/D3: J4.18, U3.15 (Q3), U4.17 (D3), U5.30 (D3), U6.15 (Y3), U7.5 (D)
/D4: J4.20, U3.16 (Q4), U4.18 (D4), U5.29 (D4), U6.14 (Y4), U7.10 (E)
/D5: J4.22, U3.17 (Q5), U4.19 (D5), U5.28 (D5), U6.13 (Y5), U7.11 (F)
/D6: J4.24, U3.18 (Q6), U4.20 (D6), U5.27 (D6), U6.12 (Y6), U7.12 (G)
/D7: J4.26, U3.19 (Q7), U4.21 (D7), U5.26 (D7), U6.11 (Y7), U7.14 (H)
/DataOut: C17.1, J3.S, R6.2
/H32: U2.5 (Q5), U10.1, U10.10, U11.3 (D0)
/H32': U10.2, U11.2 (Q0)
/HROW 0: D7.2 (A), D8.2 (A), D9.2 (A), D10.2 (A), D11.2 (A), J7.1, J8.1, RN1.7 (R6), U6.2 (A0)
/HROW 1: D17.2 (A), D18.2 (A), D19.2 (A), D20.2 (A), D21.2 (A), J7.2, J8.2, RN1.5 (R4), U6.3 (A1)
/HROW 2: D27.2 (A), D28.2 (A), D29.2 (A), D30.2 (A), D31.2 (A), J7.3, J8.3, RN1.4 (R3), U6.4 (A2)
/HROW 3: D32.2 (A), D33.2 (A), D34.2 (A), D35.2 (A), D36.2 (A), J7.4, J8.4, RN1.3 (R2), U6.5 (A3)
/HROW 4: D22.2 (A), D23.2 (A), D24.2 (A), D25.2 (A), D26.2 (A), J7.6, J8.6, RN1.6 (R5), U6.6 (A4)
/HROW 5: D12.2 (A), D13.2 (A), D14.2 (A), D15.2 (A), D16.2 (A), J7.9, J8.9, RN1.2 (R1), U6.7 (A5)
/M2: J1.5, U9.5, U12.6 (Q4)
/M4: J1.3, U9.4, U12.5 (Q3)
/M8: J1.1, U9.3, U12.4 (Q2)
/M16: J4.3, U7.7 (Clk), U12.3 (Q1)
/RAMHIDE: J4.7, RN3.4 (R3), U3.22 (~OE)
/RDY: RN2.4 (R3), U5.2 (RDY)
/Speaker: BZ1.1 (+), R8.2
/V512: D2.1 (K), D3.1 (K), D4.1 (K), U1.7 (Q7), U9.1, U9.9
/r/~w: J4.10, RN2.3 (R2), U5.34 (R/~W), U10.5
/~A13: J4.9, U4.22 (CE), U8.6
/~A15: J4.8, U4.24 (OE), U6.1 (G1), U8.2
/~HSYNC: U11.10 (Q3), U11.13 (D4)
/~HSYNC*: U11.12 (Q4), U11.14 (D5)
/~HSYNC**: J2.13, U11.15 (Q5)
/~MRC: U1.10 (~MRC), U11.5 (Q1)
/~NMI: J4.6, RN2.2 (R1), U5.6 (~NMI)
/~RESET: J4.5, U5.40 (~RES), U8.10
/~SO: RN2.5 (R4), U5.38 (~SO)
/~VSYNC: J2.14, U5.4 (~IRQ), U11.7 (Q2)
/~WR: U3.27 (~WE), U10.6, U12.9 (CK)
/~sload: U1.11 (CPC), U1.13 (CPR), U2.11 (CPC), U2.13 (CPR), U7.15 (PE), U9.6, U11.9 (Cp)
/ø1: J1.2, J1.4, J1.6, U8.13, U10.4
/ø2: J4.4, U1.14 (~OE), U2.14 (~OE), U5.36 (BE), U5.37 (ϕ0), U8.12
GND: BZ1.2 (-), C1.2, C2.2, C4.1, C5.1, C6.1, C7.1, C8.1, C9.2, C10.1, C11.1, C12.1, C13.1, C14.1, C15.1, C16.2, C17.2, H1.1, H2.1, H3.1, H4.1, J2.0, J2.5, J2.6, J2.7, J2.8, J2.10, J3.R2, J4.1, J6.2, J6.MP (MountPin), J7.5, J8.5, R1.1, R3.1, RN3.1 (common), U1.8 (GND), U2.8 (GND), U2.12 (~CE), U3.14 (GND), U4.16 (GND), U5.21 (VSS), U6.10 (GND), U7.1 (Ds), U7.6 (CE), U7.8 (GND), U8.7 (GND), U9.7 (GND), U10.7 (GND), U11.8 (GND), U12.1 (CK), U12.7 (Reset), U12.8 (VSS), U12.15 (Reset)
unnamed: C1.1, R2.1, U8.9, Y1.1
unnamed: C3.2, R4.2, R5.1
unnamed: D5.2 (A), J8.8
unnamed: D6.2 (A), J7.8
unnamed: D7.1 (K), SW1.2
unnamed: D8.1 (K), SW3.2
unnamed: D9.1 (K), SW5.2
unnamed: D10.1 (K), SW7.2
unnamed: D11.1 (K), SW9.2
unnamed: D12.1 (K), SW10.2
unnamed: D13.1 (K), SW8.2
unnamed: D14.1 (K), SW6.2
unnamed: D15.1 (K), SW4.2
unnamed: D16.1 (K), SW2.2
unnamed: D17.1 (K), SW11.2
unnamed: D18.1 (K), SW13.2
unnamed: D19.1 (K), SW15.2
unnamed: D20.1 (K), SW17.2
unnamed: D21.1 (K), SW19.2
unnamed: D22.1 (K), SW12.2
unnamed: D23.1 (K), SW14.2
unnamed: D24.1 (K), SW16.2
unnamed: D25.1 (K), SW18.2
unnamed: D26.1 (K), SW20.2
unnamed: D27.1 (K), SW21.2
unnamed: D28.1 (K), SW23.2
unnamed: D29.1 (K), SW25.2
unnamed: D30.1 (K), SW27.2
unnamed: D31.1 (K), SW29.2
unnamed: D32.1 (K), SW22.2
unnamed: D33.1 (K), SW24.2
unnamed: D34.1 (K), SW26.2
unnamed: D35.1 (K), SW28.2
unnamed: D36.1 (K), SW30.2
unnamed: D41.1 (K), R1.2
unnamed: J2.1, J2.2, J2.3, R7.2
unnamed: R3.2, R4.1, SW31.1
unnamed: R5.2, U8.11
unnamed: J6.1, SW32.1 (A)
unnamed: U1.12 (~CE), U2.9 (~RCO)
unnamed: U7.9 (Clr), U10.3
unnamed: R7.1, U7.13 (Qh)
unnamed: U8.4, U10.12
unnamed: U10.8, U10.13
unnamed: U9.12, U11.4 (D1)
unnamed: U9.8, U11.6 (D2)
unnamed: U10.11, U11.11 (D3)
unnamed: C2.1, R2.2, U8.8, U12.2 (Enable), Y1.2
VCC: C3.1, C4.2, C5.2, C6.2, C7.2, C8.2, C9.1, C10.2, C11.2, C12.2, C13.2, C14.2, C15.2, C16.1, D41.2 (A), J2.9, J4.2, J7.7, J8.7, RN1.1 (common), RN2.1 (common), SW31.2, SW32.2 (B), U1.16 (VCC), U2.10 (~MRC), U2.16 (VCC), U3.28 (VCC), U4.1 (A18), U4.2 (A16), U4.3 (A15), U4.28 (A13), U4.29 (A14), U4.30 (A17), U4.31 (PGM), U4.32 (VCC), U5.8 (VDD), U6.20 (VCC), U7.16 (VCC), U8.14 (VCC), U9.14 (VCC), U10.14 (VCC), U11.1 (~Mr), U11.16 (VCC), U12.16 (VDD)

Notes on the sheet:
$0000 | Zp, Stack, Framebuffer ------------------------------- $2000 | $4000 | 24KiB General RAM $6000 | ------------------------------- $8000 | Input Register ------------------------------- $A000 | (bus conflict) ------------------------------- $C000 | 8KiB Expansion ROM -------------------------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
Video Signal Buffer
Pixel Shifter
=524
H16
Expansion Slot
32K RAM
522-523
Keyboard
Power Input
CPU
V128
H32
Video Counters
V32
V64
Joysticks
V16
Clock
V512
V256
Reset
8K ROM

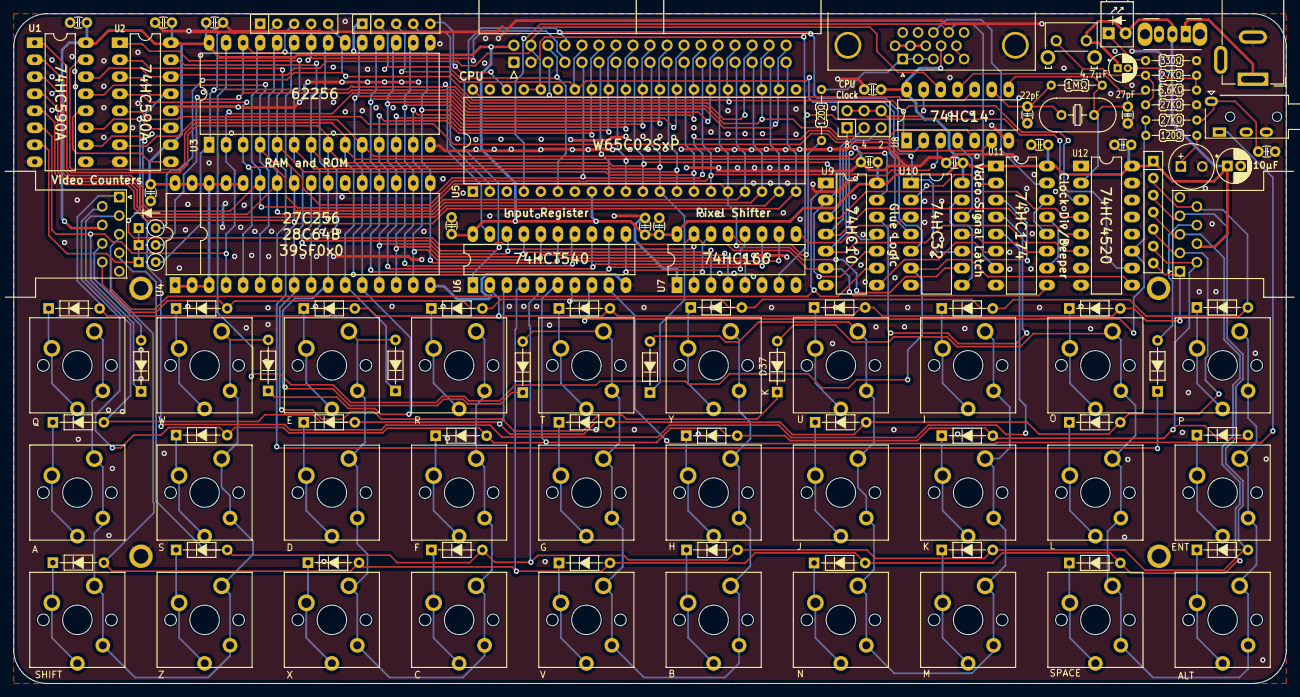
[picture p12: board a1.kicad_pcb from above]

Board: 2 copper layers, 190.0 x 100.0 mm, 126 parts (0 on the bottom side), 113 nets.

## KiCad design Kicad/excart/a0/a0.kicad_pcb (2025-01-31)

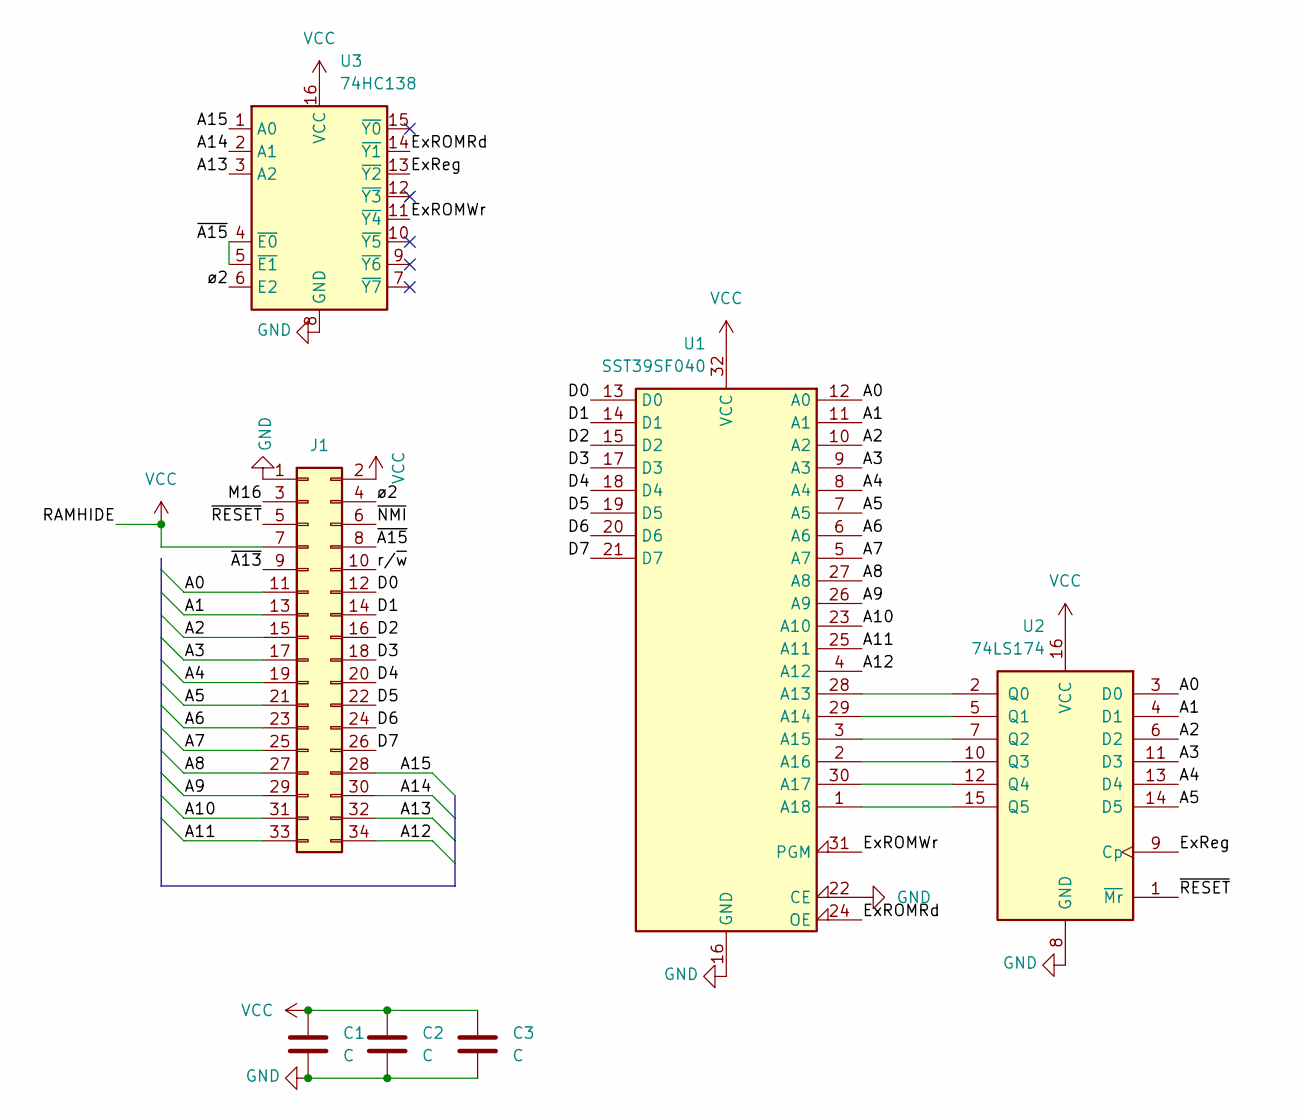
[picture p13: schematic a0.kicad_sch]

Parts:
C1, C2, C3: C; C_Disc_D3.0mm_W1.6mm_P2.50mm
J1: Conn_02x17_Odd_Even; IDC-Header_2x17_P2.54mm_Horizontal
U1: SST39SF040; DIP-32_W15.24mm_LongPads
U2: 74LS174; DIP-16_W7.62mm_LongPads
U3: 74HC138; DIP-16_W7.62mm_LongPads

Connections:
/A0: J1.11, U1.12 (A0), U2.3 (D0)
/A1: J1.13, U1.11 (A1), U2.4 (D1)
/A2: J1.15, U1.10 (A2), U2.6 (D2)
/A3: J1.17, U1.9 (A3), U2.11 (D3)
/A4: J1.19, U1.8 (A4), U2.13 (D4)
/A5: J1.21, U1.7 (A5), U2.14 (D5)
/A6: J1.23, U1.6 (A6)
/A7: J1.25, U1.5 (A7)
/A8: J1.27, U1.27 (A8)
/A9: J1.29, U1.26 (A9)
/A10: J1.31, U1.23 (A10)
/A11: J1.33, U1.25 (A11)
/A12: J1.34, U1.4 (A12)
/A13: J1.32, U3.3 (A2)
/A14: J1.30, U3.2 (A1)
/A15: J1.28, U3.1 (A0)
/D0: J1.12, U1.13 (D0)
/D1: J1.14, U1.14 (D1)
/D2: J1.16, U1.15 (D2)
/D3: J1.18, U1.17 (D3)
/D4: J1.20, U1.18 (D4)
/D5: J1.22, U1.19 (D5)
/D6: J1.24, U1.20 (D6)
/D7: J1.26, U1.21 (D7)
/ExROMRd: U1.24 (OE), U3.14 (~Y1)
/ExROMWr: U1.31 (PGM), U3.11 (~Y4)
/ExReg: U2.9 (Cp), U3.13 (~Y2)
/M16: J1.3
/r/~w: J1.10
/~A13: J1.9
/~A15: J1.8, U3.4 (~E0), U3.5 (~E1)
/~NMI: J1.6
/~RESET: J1.5, U2.1 (~Mr)
/ø2: J1.4, U3.6 (E2)
GND: C1.1, C2.1, C3.1, J1.1, U1.16 (GND), U1.22 (CE), U2.8 (GND), U3.8 (GND)
unnamed: U1.28 (A13), U2.2 (Q0)
unnamed: U1.29 (A14), U2.5 (Q1)
unnamed: U1.3 (A15), U2.7 (Q2)
unnamed: U1.2 (A16), U2.10 (Q3)
unnamed: U1.30 (A17), U2.12 (Q4)
unnamed: U1.1 (A18), U2.15 (Q5)
VCC: C1.2, C2.2, C3.2, J1.2, J1.7, U1.32 (VCC), U2.16 (VCC), U3.16 (VCC)

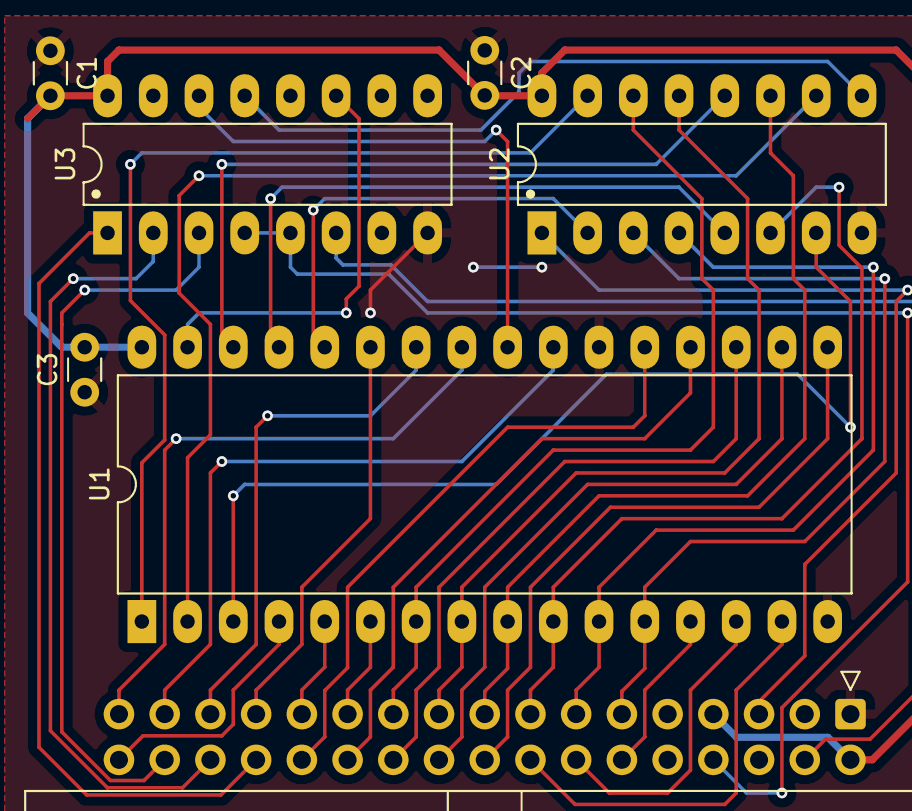
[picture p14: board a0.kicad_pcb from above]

Board: 2 copper layers, 7 parts (0 on the bottom side), 38 nets.

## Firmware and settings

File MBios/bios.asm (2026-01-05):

# -------------------------
.cpu 65c02
# Global Temp Registers
.zp r0
.zp r1
.zp r2
.zp r3
.zp r4
.zp r5
.zp r6
.zp r7
.zp r8
.zp r9
.zp rA
.zp rB
.zp rC
.zp EXTRATBL 2
.zp CPUFreq
.zp IRQ 3
.zp NMI 3

#.zp FSIZE 2 using BotPTR for now instead


.val MAXSIZE $6000

.org [$E000]
  .asm stdio
  .asm edit
  .asm lang
  
.zp FNAME 9
.zp RUNCODE 4
.val InputSize 63
.zp Input InputSize+1
.zp InputL
_RESET
  sei; cld
  lda $40; sta <NMI>        # RTI
  
  # -- Clock Speed Calc, stores (clock cyles in a irq)/16 in <rF>
  ## 8 = 2Mhz
  ## 16 = 4Mhz
  ## 32 = 8Mhz
  # align with next irq
  wai
  # interrupt subroutine takes exactly 16 cycles
  lda $65; sta <IRQ+0>      # ADC zp
  lda 0;   sta <IRQ+1>      
  lda $40; sta <IRQ+2>      # RTI
  lda 1;   sta <r0>
  
  # wait loop until the end of the current irq
  ldx 0
  __wait
  inc X; bne (wait)
  
  # activate the irq subroutine
  lda 0
  clc
  cli
  wai
  sta <CPUFreq>
  
  jsr [STDIOINIT]
  
  lda <RUNCODE+0>;cmp 'R'; bne (cold)
  lda <RUNCODE+1>;cmp 'u'; bne (cold)
  lda <RUNCODE+2>;cmp 'n'; bne (cold)
  lda <RUNCODE+3>;cmp '!'; bne (cold)
    bra (warm)
  __cold
  jsr [Edit_New]
  stz <FNAME>
  __warm
  lda 'R'; sta <RUNCODE+0>
  lda 'u'; sta <RUNCODE+1>
  lda 'n'; sta <RUNCODE+2>
  lda '!'; sta <RUNCODE+3>
  
_INIT
  lda 32; jsr [BEEP]
  lda 24; jsr [BEEP]
  
  lda string1.lo; sta <r4>
  lda string1.hi; sta <r5>
  jsr [SOUT]
  clc; lda <CPUFreq>; lsr A; lsr A; adc $30; jsr [COUT]
  lda string2.lo; sta <r4>
  lda string2.hi; sta <r5>
  jsr [SOUT]
  
  
  # By default EXTRATBL points to a zero byte within itself
  lda EXTRATBL.lo+1; sta <EXTRATBL>
  lda 0; sta <EXTRATBL+1>
  
  #lda TestCmdTable.lo; sta <EXTRATBL+0>
  #lda TestCmdTable.hi; sta <EXTRATBL+1>
  
  __CartRunCheck
  # Check for CART-RUN
  lda [$C000]; cmp 'C'; bne (done)
  lda [$C001]; cmp 'A'; bne (done)
  lda [$C002]; cmp 'R'; bne (done)
  lda [$C003]; cmp 'T'; bne (done)
  lda [$C004]; cmp '-'; bne (done)
  lda [$C005]; cmp 'R'; bne (done)
  lda [$C006]; cmp 'U'; bne (done)
  lda [$C007]; cmp 'N'; bne (done)
    jsr [$C008]
  ___done
  __CartCmdCheck
  # Check for CART-CMD
  lda [$C000]; cmp 'C'; bne (done)
  lda [$C001]; cmp 'A'; bne (done)
  lda [$C002]; cmp 'R'; bne (done)
  lda [$C003]; cmp 'T'; bne (done)
  lda [$C004]; cmp '-'; bne (done)
  lda [$C005]; cmp 'C'; bne (done)
  lda [$C006]; cmp 'M'; bne (done)
  lda [$C007]; cmp 'D'; bne (done)
    lda $08; sta <EXTRATBL+0>
    lda $C0; sta <EXTRATBL+1>
  ___done
    
_MAIN
  jsr [cFILE]
  jsr [cHELP]
  stz <InputL>
  lda '>'; jsr [COUT]
    
__fim
  lda 0
  jsr [CIN]; beq (fim)
  
  cmp LF; beq (lf)
  cmp BS; beq (bs)
  
  pha
  lda <InputL>; cmp InputSize; beq (inputfull)
  pla;pha
  jsr [COUT]
  pla
  ldx <InputL>; sta <Input+X>; inc <InputL>
bra (fim)
___lf
  jsr [COUT]
  lda  CR; jsr [COUT]
  ldx <InputL>; lda $00; sta <Input+X>
  jsr [CmdRun]
  stz <InputL>
  lda '>'; jsr [COUT]
bra (fim)
___bs
  pha
  lda <InputL>; beq (inputfull)
  dec <InputL>
  pla
  jsr [COUT]
bra (fim)
___inputfull
  lda BEL; jsr [COUT]
bra (fim)

_hInputH8
	# -- Parse an 8bit value hex value from input
	# in:
	#	X→Input Index
	# out:
	#	X→Incremented Input Index
	#	C→Successful
	#	A→Parsed Value
	
	dec X
	__skipspaces
		inc X
		cpx InputSize-1; bcs (fail)
		lda <Input+X>; beq (fail)

	cmp ' '; beq (skipspaces)
	
	# Read Input
	lda <Input+X>; sta <0>
	inc X
	lda <Input+X>; sta <1>
	inc X
	
	phx; lda <0>; ldx <1>
	jsr [AsciiToHex]
	plx; bcc (fail)
	
	__succ
	sec; rts
	__fail
	clc; rts

_CMDIN
  ldx Input.lo
  ldy <InputL>
rts

_cUNKNOWN
  SPrint string_unknown
rts

_cHELP
  SPrint string_help
  sei
  ldx 0
  __loop
    lda [CmdTable+X]; beq (done)
    phx
    SPrint string_list
    plx
    ldy 6
    ___print
      phy; phx; lda [CmdTable+X]
      jsr [COUT]; plx; ply
    sei; inc X; dec Y; bne (print)
    inc X; inc X
  bne (loop)
  ___done
  ldy 0
  __extraloop
    lda [<EXTRATBL>+Y]; beq (done)
    phy
    SPrint string_list
    ply
    ldx 6
    ___print
      phy;phx; lda [<EXTRATBL>+Y]
      
      # Reject Invalid Characters
      beq (bad)
      cmp $7F; bcs (bad)
      cmp $20; bcc (bad)
      jsr [COUT]; plx; ply
    sei; inc Y; dec X; bne (print)
    inc Y; inc Y
  bne (extraloop)
  __done
  cli
  lda CR; jsr [COUT]
  lda LF; jsr [COUT]
rts
__bad
  plx; ply
  cli
  ldx 0
  
  ___send
  lda [error+X]; beq (done); phx; jsr [COUT]; plx; inc X; cpx 64; bne (send)
  ___done
  
  lda EXTRATBL.lo+1; sta <EXTRATBL>
  lda 0; sta <EXTRATBL+1>
rts
___error
.byte CR,LF, CHI,' ERROR ',CNO,' bad cartridge',CR,LF,$00
#jmp [MAIN]


_cFILE
  lda <FNAME>; beq (unnamedfile)
  lda CHI; jsr [COUT]
  lda FNAME.lo; sta <r4>; stz <r5>
  jsr [SOUT]
  lda CNO; jsr [COUT]
  bra (continue)
  __unnamedfile
  lda txtun.lo; sta <r4>; lda txtun.hi; sta <r5>
  jsr [SOUT]
  __continue
  lda ' '; jsr [COUT]
  sec
  lda <BotPTR+0>; sbc $2000.lo; sta <r0>
  lda <BotPTR+1>; sbc $2000.hi; sta <r1>
  jsr [BinToDecPrint]
  lda txt2.lo; sta <r4>
  lda txt2.hi; sta <r5>
  jsr [SOUT]
rts
__txt2
.byte ' bytes',CR,LF,CR,LF,$00
__txtun
.byte "<untitled>"

_cCLEAR
  lda FF; jsr [COUT]
rts

_cNEW
  jsr [Edit_New]
  lda $2000.lo; sta <BotPTR+0>
  lda $2000.hi; sta <BotPTR+1>
  stz <FNAME>
  jmp [cFILE]

_cNAME
  ldx 5
  ldy 0
  
  __findstart
    lda <Input+X>; beq (done)
    cmp ' '; bne (cmdStart)
  inc X; cpx <InputL>; beq (done); bra (findstart)
  __cmdStart
    lda <Input+X>; sta [FNAME+Y]
    inc Y; inc X
  cpx <InputL>; beq (done); cpy 8; beq (done); bra (cmdStart)
  __done
  lda 0; sta [FNAME+Y]
  jmp [cFILE]

_cEDIT
	jsr [Edit]
rts

_cSEND
  lda $2000.lo; sta <r0>
  lda $2000.hi; sta <r1>
  lda <BotPTR+0>; sta <r2>
  lda <BotPTR+1>; sta <r3>
  jmp [FileOUT]
  
_cLOAD
jmp [FileIN]


# ------------------------------
# Memory Monitor Functions
_cPRUN
    # -- Run a "program" at specified address
	ldx 4
	jsr [hInputH8]; bcc (break)
		sta <r2>
	jsr [hInputH8]; bcc (break)
		sta <r1>
	lda $4C # (opcode for JMP)
	    sta <r0>
	jsr [r0]
__break
rts
_cPOKE
	ldx 4
	jsr [hInputH8]; bcc (break)
		sta <r7>
	jsr [hInputH8]; bcc (break)
		sta <r6>
		
    ldy 0
	__WriteLoop
		jsr [hInputH8]; bcc (break)
		sta [<r6>+Y]
    inc Y; bra (WriteLoop)
__break
rts
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

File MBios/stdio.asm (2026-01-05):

# -------------------------
# STDIO
#  handles basic terminal input and output functions
# -------------------------
_FONT
.bin "font"

.val FONT_0 FONT+0-32
.val FONT_1 FONT+96-32
.val FONT_2 FONT+192-32
.val FONT_3 FONT+288-32
.val FONT_4 FONT+384-32
.val FONT_5 FONT+480-32
.val FONT_6 FONT+576-32
.val FONT_7 FONT+672-32

#.asm otla

.zp Cursor  2
	.val CursorX Cursor+0
	.val CursorY Cursor+1
.zp CursorFlip 1
.zp CursorTime 1
.zp CursorColour 1
.zp ActiveFooter 1

.val KInpSize 4
.zp KInp    KInpSize

.zp KInpPtr 1
.zp KLast   5
.zp KCur    5
.zp KMod    1
.zp KTime   1
.zp KRepeat 1

# Control Codes
.val ETX $03  # Escape
.val BEL $07  # bell
.val BS  $08  # backspace
.val LF  $0A  # line feed
.val FF  $0C  # form feed
.val CR  $0D  # carriage return
.val CHI $10  # color highlight
.val CNO $11  # color normal
.val FON $12  # Footer ON
.val FOF $13  # Footer OFF
.val DEL $7F  # Delete


.val ALF   $01
.val ARI   $02
.val AUP   $03
.val ADW   $04

.val SPC ' '
.val ENT LF
.val SHF 0
.val ALT 0
.val HSH $23
.val QOT $27


_KMapR1
.byte 'q','a', 0 ,'z','s','w',0,0 # normal
.byte 'Q','A', 0 ,'Z','S','W',0,0 # shift
.byte '1','@', 0 ,'*',HSH,'2',0,0 # alt
.byte ETX,ALF,0 ,'~',ADW,AUP,0,0 # shift+alt

_KMapR2
.byte 'e','d','x','c','f','r',0,0 # normal
.byte 'E','D','X','C','F','R',0,0 # shift
.byte '3','$',$22,QOT,'%','4',0,0 # alt
.byte '^',ARI, 0 , 0 ,'{','|',0,0 # shift+alt

_KMapR3
.byte 't','g','v','b','h','y',0,0 # normal
.byte 'T','G','V','B','H','Y',0,0 # shift
.byte '5','&',',','.','-','6',0,0 # alt
.byte '_','}',';',':','<', 0 ,0,0 # shift+alt

_KMapR4
.byte 'u','j','n','m','k','i',0,0 # normal
.byte 'U','J','N','M','K','I',0,0 # shift
.byte '7','+','?','!','(','8',0,0 # alt
.byte  0 ,'=','/','\','[', 0 ,0,0 # shift+alt

_KMapR5
.byte 'o','l',SPC, 0 ,ENT,'p',0,0 # normal
.byte 'O','L',SPC, 0 ,ENT,'P',0,0 # shift
.byte '9',')', 0 , 0 ,BS ,'0',0,0 # alt
.byte  0 ,']', 0 , 0 , 0 , 0 ,0,0 # shift+alt

_KMapJ1
.byte 'a','b','c','d','e','f',0,0 # normal
.byte 'a','b','c','d','e','f',0,0 # normal
.byte 'a','b','c','d','e','f',0,0 # normal
.byte 'a','b','c','d','e','f',0,0 # normal

_KMapJ2
.byte 'A','B','C','D','E','F',0,0 # normal
.byte 'A','B','C','D','E','F',0,0 # normal
.byte 'A','B','C','D','E','F',0,0 # normal
.byte 'A','B','C','D','E','F',0,0 # normal

##
_KRowRead
  # r01 INPUT: holds pointer to the row's keymap
  # r2  INPUT: holds the row read value
  # r3  TEMP:  is a counter
  lda <r2>; xor <r3>; and <r2>; sta <r2>
  
  lda 6; sta <r3>
  ldx <KInpPtr>; cpx KInpSize; beq (return)
  ldy <KMod>
  __loop
    lsr <r2>
    lda [<r0>+Y]
    beq (notpressed); bcc (notpressed)
      # pressed logic goes here
      inc X; sta <KInp-1+X>; cpx KInpSize; beq (return)
    __notpressed
    inc Y
  dec <r3>; bne (loop)
  __return
  stx <KInpPtr>
rts

# ----------------------------------------------------------------
# KeyBoard Interrupt Routine
_KReadINT
  pha; phx; phy
  lda <r0>; pha
  lda <r1>; pha
  lda <r2>; pha
  lda <r3>; pha
  lda <r4>; pha; stz <r4>
  
  .val KRow1 %1001_1111_1111_1110
  .val KRow2 %1001_1111_1111_1101
  .val KRow3 %1001_1111_1111_1011
  .val KRow4 %1001_1111_1111_0111
  .val KRow5 %1001_1111_1110_1111
  .val KJoy1 %1000_1111_1111_1111
  .val KJoy2 %1001_0111_1111_1111
  
  __modifiers
  lda [KRow1]; sta <KCur+0>
  lda [KRow2]; sta <KCur+1>
  lda [KRow3]; sta <KCur+2>
  lda [KRow4]; sta <KCur+3>
  lda [KRow5]; sta <KCur+4>
  
  
  lda <KCur+0>; and %00_000100; sta <r0>
  lda <KCur+4>; and %00_001000; ora <r0>
  asl A; sta <KMod>
  
  __row1
  lda <KLast+0>; sta <r3>
  lda <KCur+0>; cmp <KLast+0>; beq (row2)
    inc <r4>
    sta <r2>; sta <KLast+0>
    lda KMapR1.lo; sta <r0>
    lda KMapR1.hi; sta <r1>
    jsr [KRowRead]
  __row2
  #jmp [blink]
  lda <KLast+1>; sta <r3>
  lda <KCur+1>; cmp <KLast+1>; beq (row3)
    inc <r4>
    sta <r2>; sta <KLast+1>
    lda KMapR2.lo; sta <r0>
    lda KMapR2.hi; sta <r1>
    jsr [KRowRead]
  __row3
  lda <KLast+2>; sta <r3>
  lda <KCur+2>; cmp <KLast+2>; beq (row4)
    inc <r4>
    sta <r2>; sta <KLast+2>
    lda KMapR3.lo; sta <r0>
    lda KMapR3.hi; sta <r1>
    jsr [KRowRead]
  __row4
  lda <KLast+3>; sta <r3>
  lda <KCur+3>; cmp <KLast+3>; beq (row5)
    inc <r4>
    sta <r2>; sta <KLast+3>
    lda KMapR4.lo; sta <r0>
    lda KMapR4.hi; sta <r1>
    jsr [KRowRead]
  __row5
  lda <KLast+4>; sta <r3>
  lda <KCur+4>; cmp <KLast+4>; beq (blink)
    inc <r4>
    sta <r2>; sta <KLast+4>
    lda KMapR5.lo; sta <r0>
    lda KMapR5.hi; sta <r1>
    jsr [KRowRead]
  __blink
  lda 30; cmp <CursorTime>; bne (noblink)
    inc <CursorFlip>
    stz <CursorTime>
    ldy 7; ldx $0F
  lda <CursorY>; inc A; inc A; sta <r1>
  lda <CursorX>; lsr A; bcs (right)
    ldx $F0
  ___right
  asl A; asl A; asl A; sta <r0>
  ___loop
    txa; xor [<r0>+Y]; sta [<r0>+Y]
  dec Y; bpl (loop)
  ___noblink
  inc <CursorTime>
  
  lda <r4>; beq (nopress)
    stz <KRepeat>; lda $40; sta <KTime>
    ldx <KInpPtr>; beq (nopress)
    lda <KInp-1+X>; beq (nopress)
    sta <KRepeat>; inc X
  __nopress
  inc <KTime>; lda %0000_1111; and <KTime>; bne (norepeat)
    lda <KRepeat>; beq (norepeat)
    inc <KInpPtr>; ldx <KInpPtr>
    sta <KInp+X>
    lda $00; sta <KTime>
  __norepeat
  
  pla; sta <r4>
  pla; sta <r3>
  pla; sta <r2>
  pla; sta <r1>
  pla; sta <r0>
  ply; plx; pla
rti

_STDIOINIT
  stz <ActiveFooter>
  stz <KInpPtr>
  stz <CursorColour>
  
  # Setup Keyboard Routine
  sei
  lda $4C; sta <IRQ>        # JMP abs
  lda KReadINT.lo; sta <IRQ+1>
  lda KReadINT.hi; sta <IRQ+2>
  cli
rts

# ----------------------------------------------------------------
# Pitched Beep
_BEEP
  phx; phy
  # Frequency is based on rF, so the value will be constant
  .val belLength 100
  pha
  sei
  ldy belLength
  __ouloop
    stz [$FFFF]
    ldx <CPUFreq>
    __inloop
      pla; pha
      __ininloop
      dec A; bne (ininloop)
    dec X; bne (inloop)
  dec Y; bne (ouloop)
  pla
  ply; plx
  cli
rts



# ----------------------------------------------------------------
# Character Input from keyboard
_CIN
  phx
  #phx; phy
  ldx <KInpPtr>; cpx 0; beq (none)
    dec <KInpPtr>; lda <KInp-1+X>; 
    plx
    ora 0
    #ply; plx; 
    rts  
  __none
  plx
  lda 0
  #txa
  #ply; plx
rts
.macro SPrint
    lda {0}.lo; sta <r4>
    lda {0}.hi; sta <r5>
    jsr [SOUT]
.endmacro
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

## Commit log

2024-11-14 add kicad, emulator, bios files
    [a0.kicad_pcb, a0.kicad_sch]
2024-11-25 pcb,bios,font improvements
    [a0.kicad_pcb, a0.kicad_sch]
2024-11-27 update pcb
    [a0.kicad_pcb]
2024-12-16 update system logic
    [a0.kicad_sch]
2024-12-16 file update
    [a0.kicad_pcb, a0.kicad_sch]
2025-01-08 Update pcb and readme
    [a0-B_Cu.gbr, a0-B_Mask.gbr, a0-B_Paste.gbr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]
2025-01-08 update render image
    [a1.kicad_pcb]
2025-01-16 tweak pcb, change key layout
    [a1.kicad_pcb, a1.kicad_sch]
2025-01-19 Silkscreen tweaks
    [a1-B_Cu.gbr, a1-B_Mask.gbr, a1-B_Paste.gbr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]
2025-01-31 Updated PCBs and Code
    [a0.kicad_pcb, a0.kicad_sch, a1.kicad_pcb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]
2025-02-06 tweak clock circuit
    [a1.kicad_pcb, a1.kicad_sch]
2025-02-06 fix PJ-320A (headphone jack) footprint
    [a1.kicad_pcb]
2025-04-01 Circuit Tweaks
    [a2-B_Cu.gbr, a2-B_Mask.gbr, a2-B_Paste.gbr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]
2025-04-05 add 2 more m2 screw posts
    [a2.kicad_pcb, a2.kicad_sch]
2025-04-06 Big a2 update
    [a2.kicad_pcb, a2.kicad_sch, keyboard.kicad_sch]
2025-04-10 Specify MCP100 H boundout version (why are there 2)
    [a2.kicad_pcb, a2.kicad_sch, keyboard.kicad_sch]
2025-04-10 tweak resitor values
    [a2.kicad_pcb, a2.kicad_sch, keyboard.kicad_sch]
2025-04-11 fix bios bug, update readme
    [bios.asm]
2025-07-05 add html bom
    [a2.kicad_pcb, keyboard.kicad_sch]
2025-07-05 Add interactive BOM link to README
2025-12-11 switch to SDL_QueueAudio
2025-12-15 switch cpu to submodule
2026-01-05 fix unitialized activefooter variable
    [stdio.asm]
2026-01-05 SETCURSOR/GETCURSOR, FOOTER and Bugfixes
    [bios.asm, stdio.asm]
